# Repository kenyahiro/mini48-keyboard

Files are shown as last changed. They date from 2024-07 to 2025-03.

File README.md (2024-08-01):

# このキーボードについて
このキーボードは 19mmピッチ 48キーのロープロファイルキーボードです。
キースイッチは [kailh choc V1用ソケット](https://www.kailhswitch.com/mechanical-keyboard-switches/box-switches/choc-type-hot-swap-socket.html) を使用します。

マイコンには [AE-RP2040](https://akizukidenshi.com/catalog/g/g117542/) を使用します。

ファームウェアは [kmk_firmware](https://github.com/KMKfw/kmk_firmware) を使います。

# 部品表

| レフデス | 型名 | 数量 | 備考 |
|---|---|---|---|
| D1 - D48 | 1N4148W | 48 | |
| SW1 - SW48 | CPG135001S30 | 48 | Choc Type Hot Swap Socket |
| U1 | AE-RP2040 | 1 | RP2040マイコンボード |

この他に, kailh choc V1キースイッチ、 choc V1用キーキャップが必要です。
また、 基板を固定するためM2の支柱とネジを使います。

# マイコンの動作確認
組み立ての前にマイコンボードの動作確認を行います。
マイコンボードに [CircuitPython](https://circuitpython.org/board/raspberry_pi_pico/) を書き込みます。

書き込み後、 [Thonny](https://thonny.org/)等でCircuitPythonが動いていることを確認します。

# 組み立て

## ダイオードのハンダ付け
はじめに, D1 - D48 のダイオードをハンダ付けします。
アノードとカソードの向きを間違えないように注意してください。

## キーソケットのハンダ付け
次にkailh choc V1用キーソケットをハンダ付けします。
キーソケットには向きがあります。 基板のシルクを参考にして、間違えないようにハンダ付けしてください。

## マイコンボードの取り付け
マイコンボードの取り付け方法は、直付け または ピンソケット の選択ができます。

直付けの場合、キーボード裏の厚みを薄くできます。しかし、マイコンボードが故障したときに交換が難しくなります。

ピンソケットを使用した場合、キーボード裏の厚みがピンソケット分増加します。マイコンボードの交換は容易です。

### マイコンボードの組み立て

マイコンボードに 細ピンヘッダ(AE-RP2040付属) または [基板用リードフレーム](https://akizukidenshi.com/catalog/g/g114883/) をハンダ付けします。

細ピンヘッダをハンダ付けする場合、 ブレッドボードを使うとハンダ付けしやすいです。

リードフレームをハンダ付けする場合、 垂直になるようにハンダ付けします。まず1ピンだけ仮止めして、角度を調整します。
垂直になったら、残りのピンをハンダ付けします。

念のため、マイコンボードの裏側に[ポリイミドテープ](https://akizukidenshi.com/catalog/r/rpolyimid/)を貼って絶縁します。

### マイコンボードの取り付け(直付けの場合)
マイコンボードの取り付け前に、ダイオードとキーソケットの向き、ハンダ不良が無いことを確認します。
特に、 マイコンボードの下になる D35, D36, SW35, SW36 は注意して確認します。

U1のスルーホールにマイコンボードを刺し込みます。マイコンボードの裏側とダイオード、キーソケットが接触していないことを確認します。

マイコンボードのハンダ付けをします。まず、1つのピンをハンダ付けして仮止めします。
マイコンボードが水平になっていることを確認します。水平でない場合、ハンダゴデで仮止めしたピンのハンダを温めて、水平になるように修正します。

仮止めでマイコンボードが水平になっていることを確認できたら、残りのピンをハンダ付けします。

### マイコンボードの取り付け(ソケットの場合)
[ピンソケット](https://akizukidenshi.com/catalog/g/g100241/)はマイコンボードのピン数に合せてカットします。

基板にピンソケットをハンダ付けします。ピンソケットは垂直になるようにハンダ付けします。まず1ピンだけ仮止めして、角度を調整します。
垂直になったら、残りのピンをハンダ付けします。

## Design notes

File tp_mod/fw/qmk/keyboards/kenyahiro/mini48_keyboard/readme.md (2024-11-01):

# mini48-keyboard

A customizable Hotswap keyboard.

* Keyboard Maintainer: [kenyahiro](https://github.com/kenyahiro)

Make example for this keyboard (after setting up your build environment):

    make kenyahiro/mini48-keyboard:default

## Bootloader

Enter the bootloader in 3 ways:

* **Bootmagic reset**: Hold down the key at (0,0) in the matrix
* **Physical reset button**: Double tap the reset button on the back of the PCB
* **Keycode in layout**: Press the key mapped to `QK_BOOT` if it is available

See the [build environment setup](https://docs.qmk.fm/#/getting_started_build_tools) and the [make instructions](https://docs.qmk.fm/#/getting_started_make_guide) for more information. Brand new to QMK? Start with our [Complete Newbs Guide](https://docs.qmk.fm/#/newbs).

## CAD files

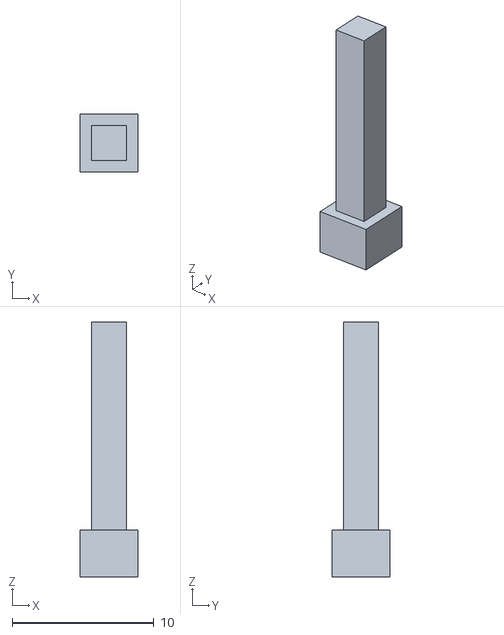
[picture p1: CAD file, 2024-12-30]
case/mini48-keyboard-case/tp-stem_t440-Body.stl
4.10 x 4.10 x 18.0

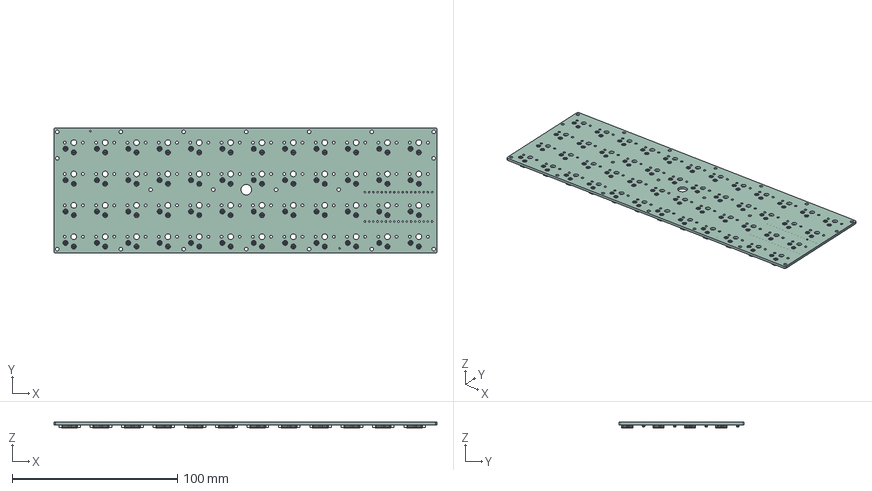
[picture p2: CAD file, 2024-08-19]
sch/mini48-keyboard/mini48-keyboard.step
232.0 x 76.0 x 3.45 mm
choc x 48
D_SOD_123 x 48
mini48-keyboard_PCB

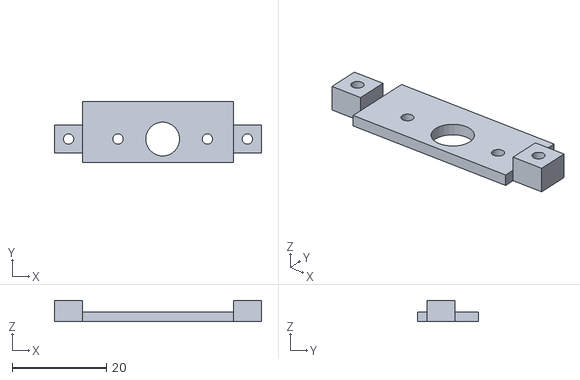
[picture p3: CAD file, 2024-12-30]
case/mini48-keyboard-case/tp_stay2-Body.stl
44.0 x 13.0 x 4.50

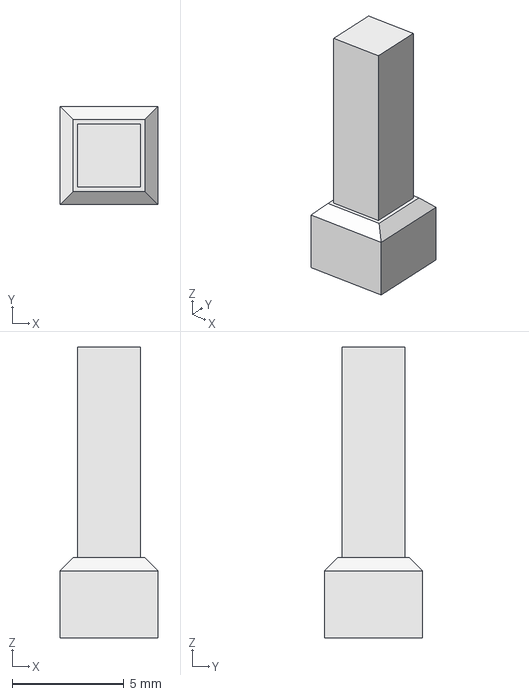
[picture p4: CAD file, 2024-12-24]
case/mini48-keyboard-case/tp-stem.FCStd
4.40 x 4.40 x 13.0 mm

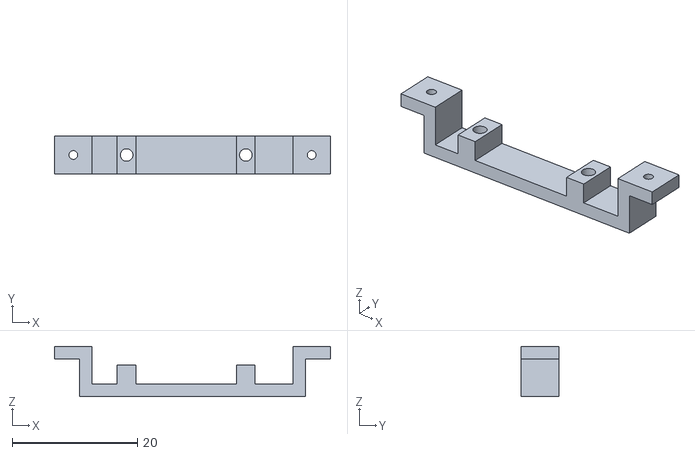
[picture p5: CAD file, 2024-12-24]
case/mini48-keyboard-case/tp_stay-Body.stl
44.0 x 6.00 x 8.00

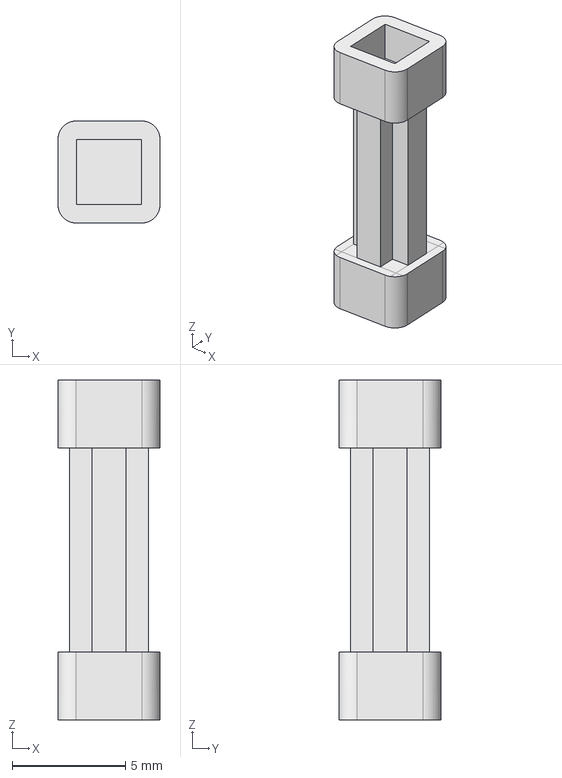
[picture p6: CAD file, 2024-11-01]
case/mini48-keyboard-case/tp-stem-test.FCStd
4.50 x 4.50 x 15.0 mm

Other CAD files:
case/mini48-keyboard-case/tp-stem_t440.FCStd
case/mini48-keyboard-case/tp_stay2.FCStd
case/mini48-keyboard-case/tp_stay.FCStd

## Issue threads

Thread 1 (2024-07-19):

コンスルーピンが使えない

kenyahiro, 2024-07-19:
マイコン基板のスルーホール径が大きいため、コンスルーピンが使えません。
通常のピンヘッダ、ICソケットは問題ありません。

コンスルーピンの推奨径は、Φ0.85 です。
https://www.mac8sdk.co.jp/uploads/entry_meta/file_value/1117/mac8_2022r103_jp-xb.pdf

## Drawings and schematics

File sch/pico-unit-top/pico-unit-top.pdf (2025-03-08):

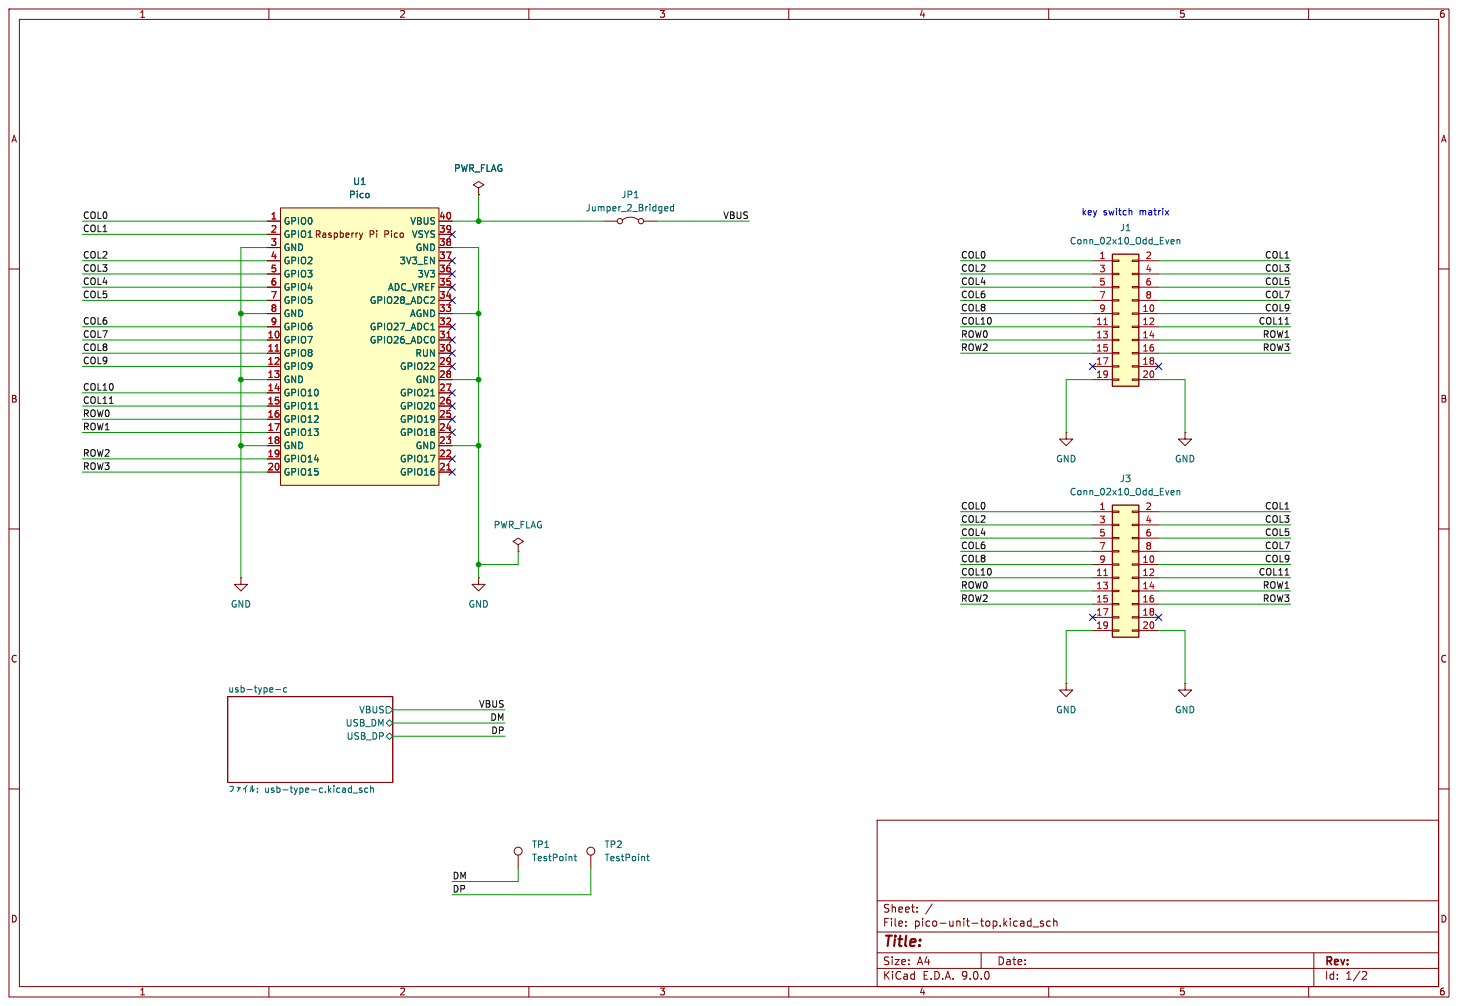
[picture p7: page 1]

VBUS
Id: 1/2 Title: File: pico-unit-top.kicad_sch Sheet: / USB_DM
USB_DP

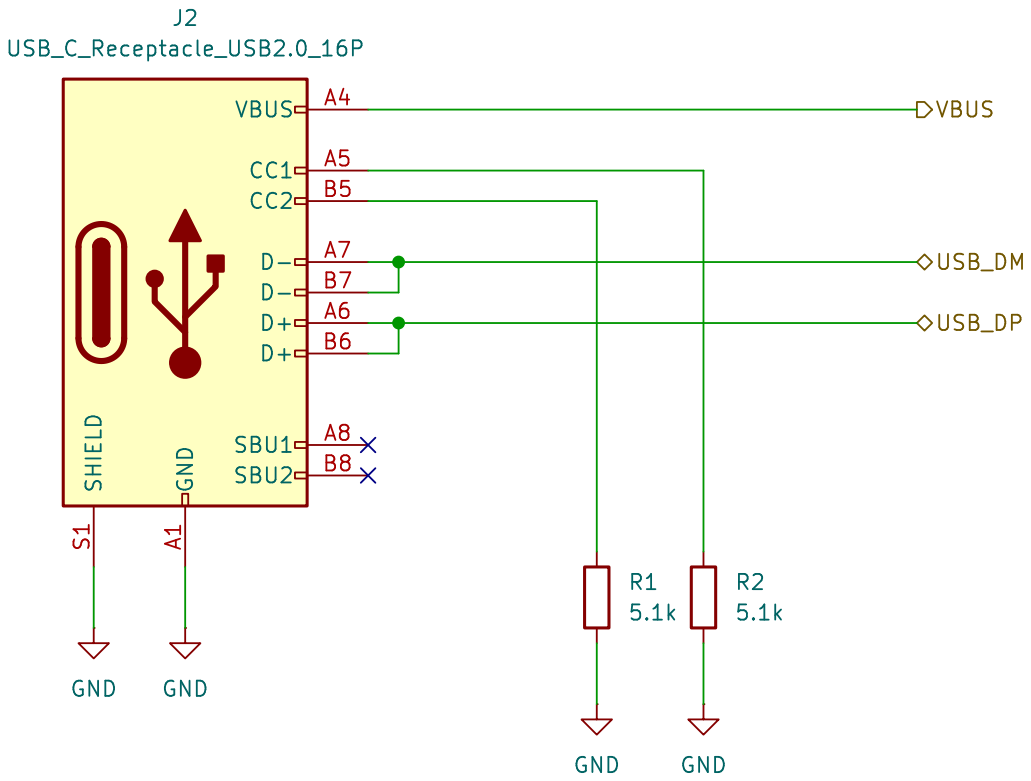
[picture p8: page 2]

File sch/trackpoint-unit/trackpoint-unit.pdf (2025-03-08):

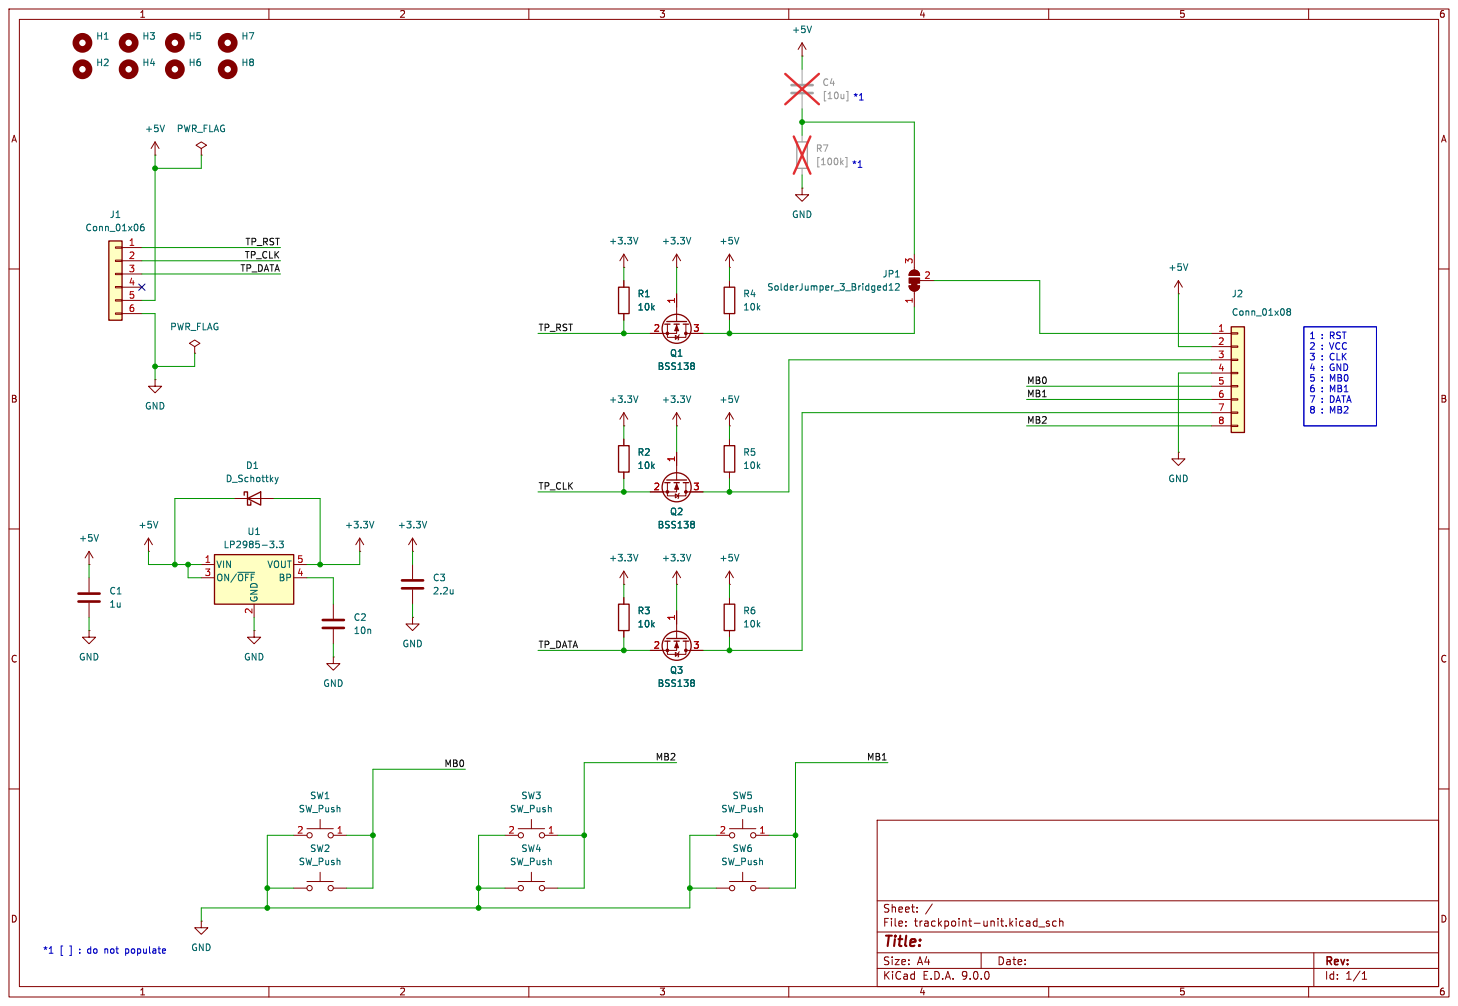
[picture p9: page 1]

Id: 1/1 Title: File: trackpoint-unit.kicad_sch Sheet: / R6

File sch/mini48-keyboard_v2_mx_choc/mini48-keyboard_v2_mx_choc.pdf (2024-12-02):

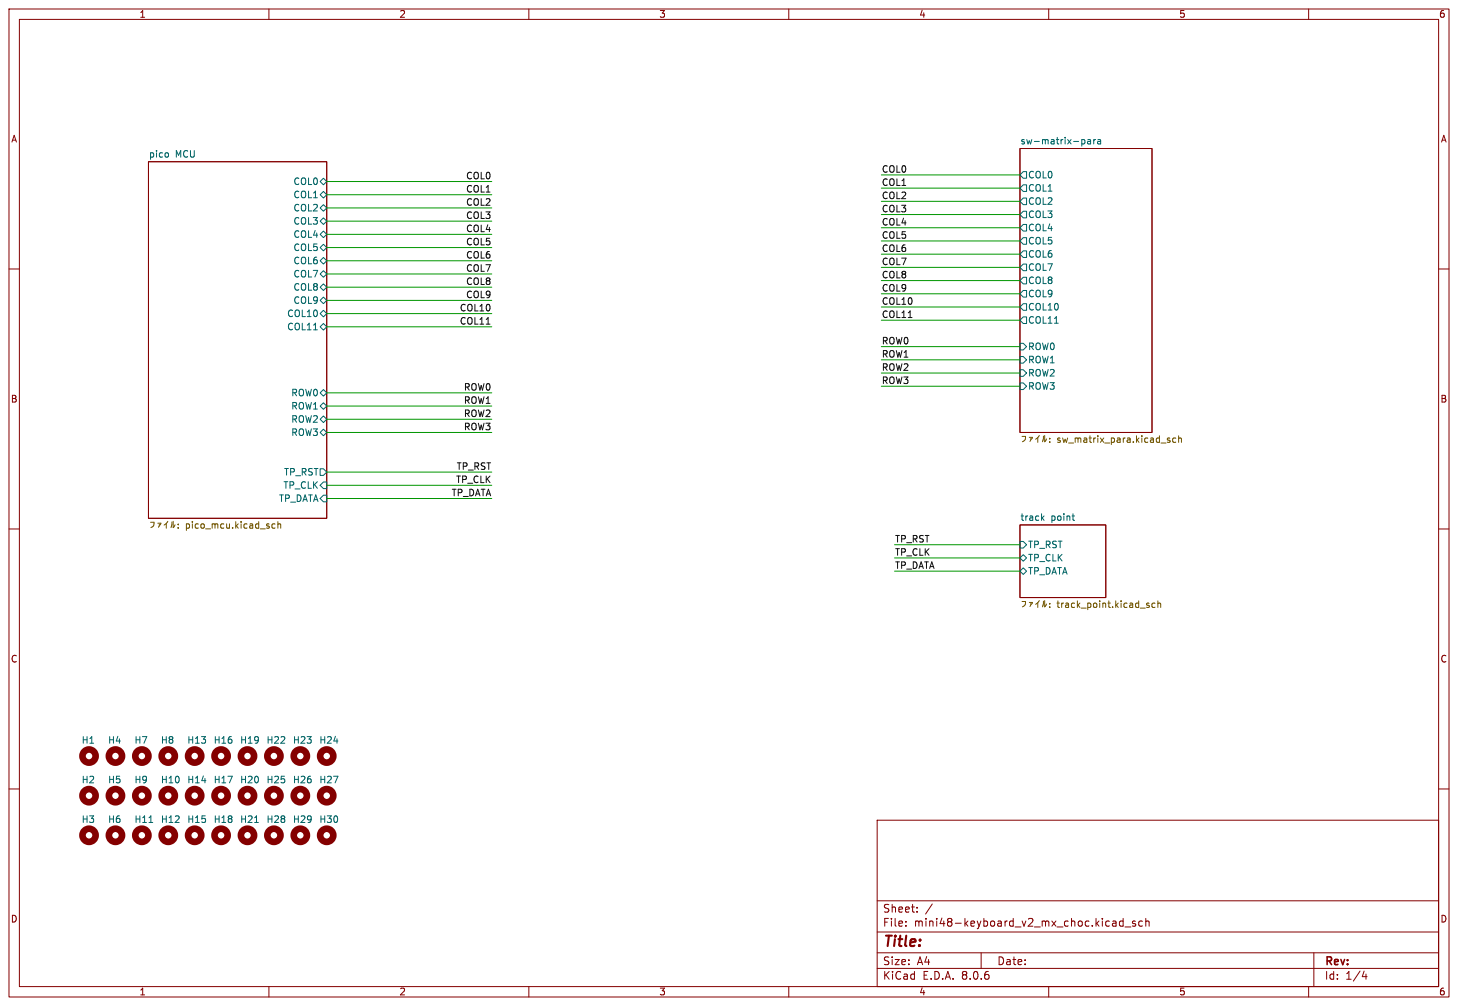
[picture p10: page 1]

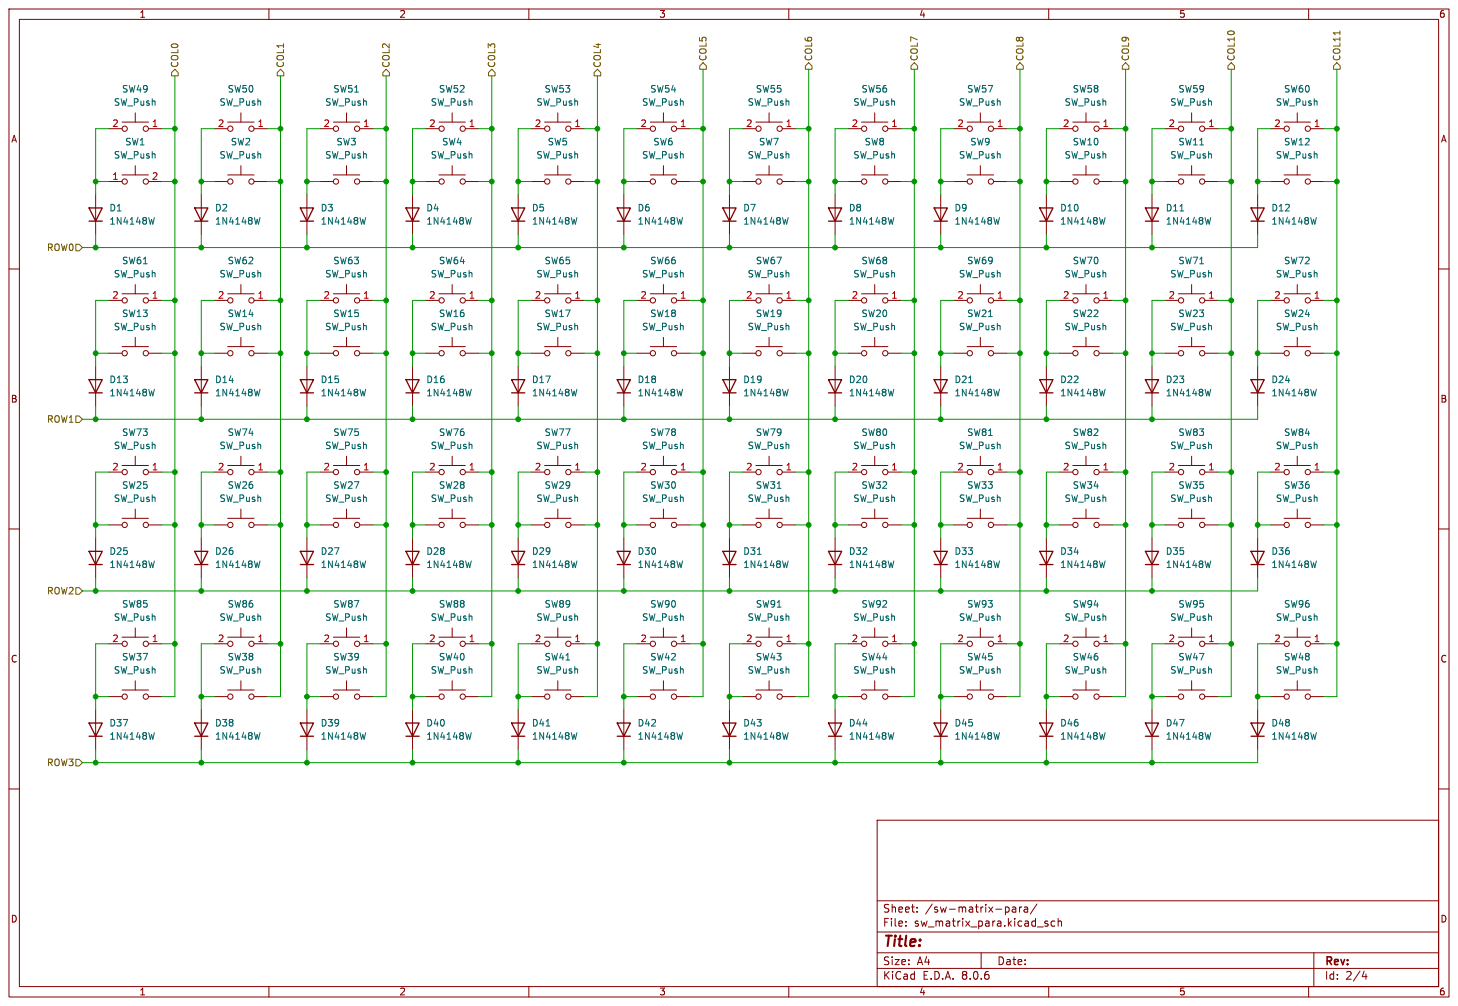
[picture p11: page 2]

Id: 2/4 Title: File: sw_matrix_para.kicad_sch Sheet: /sw-matrix-para/

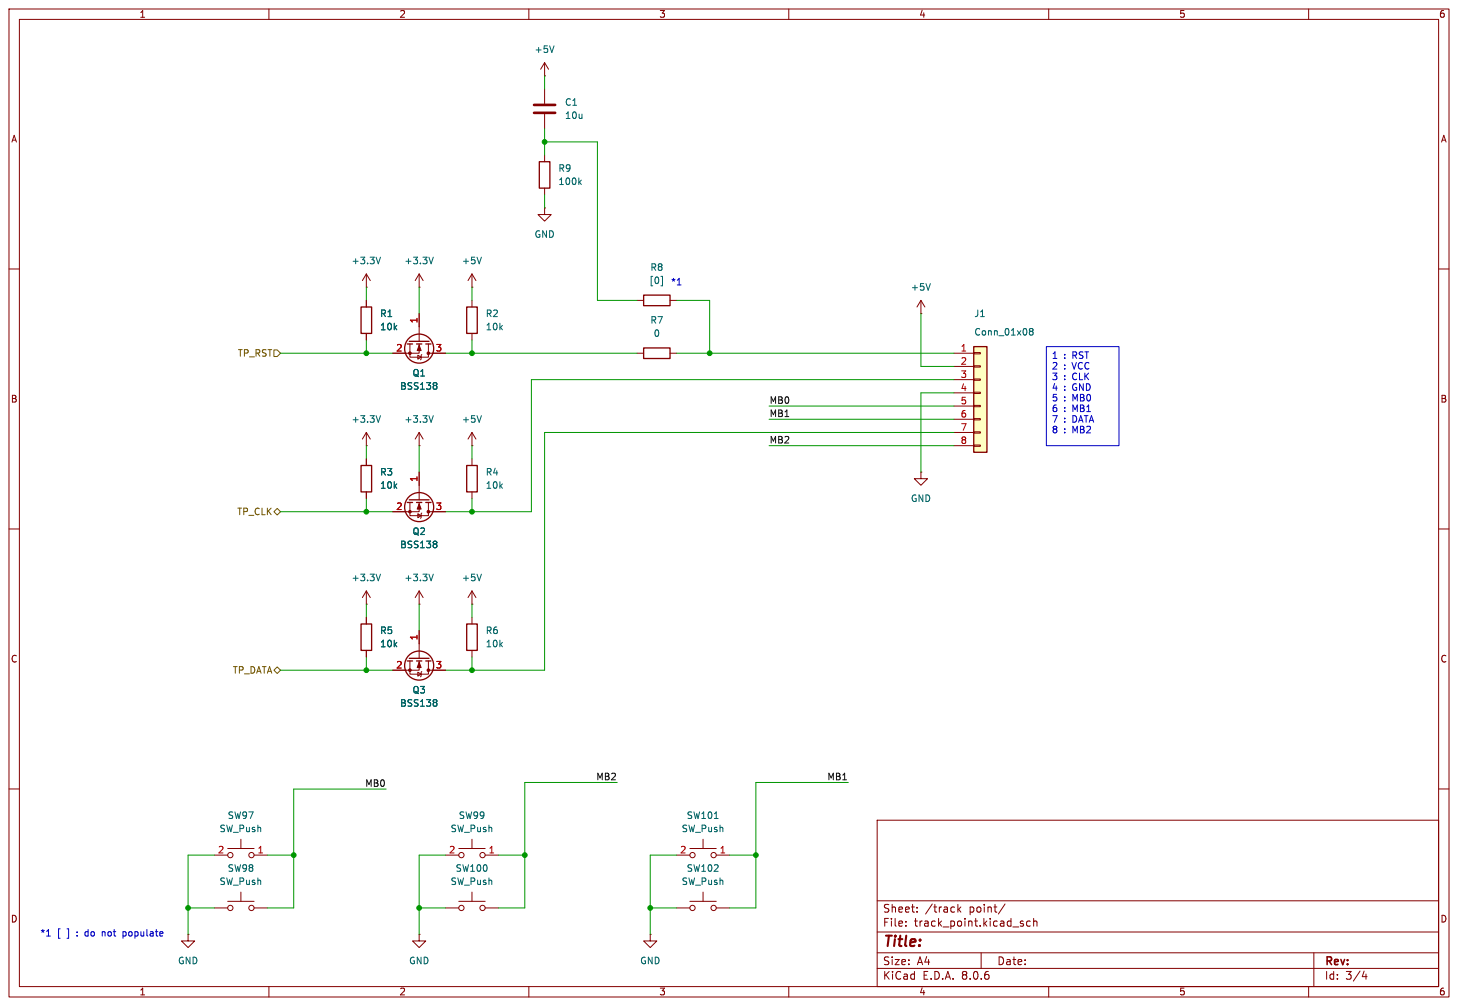
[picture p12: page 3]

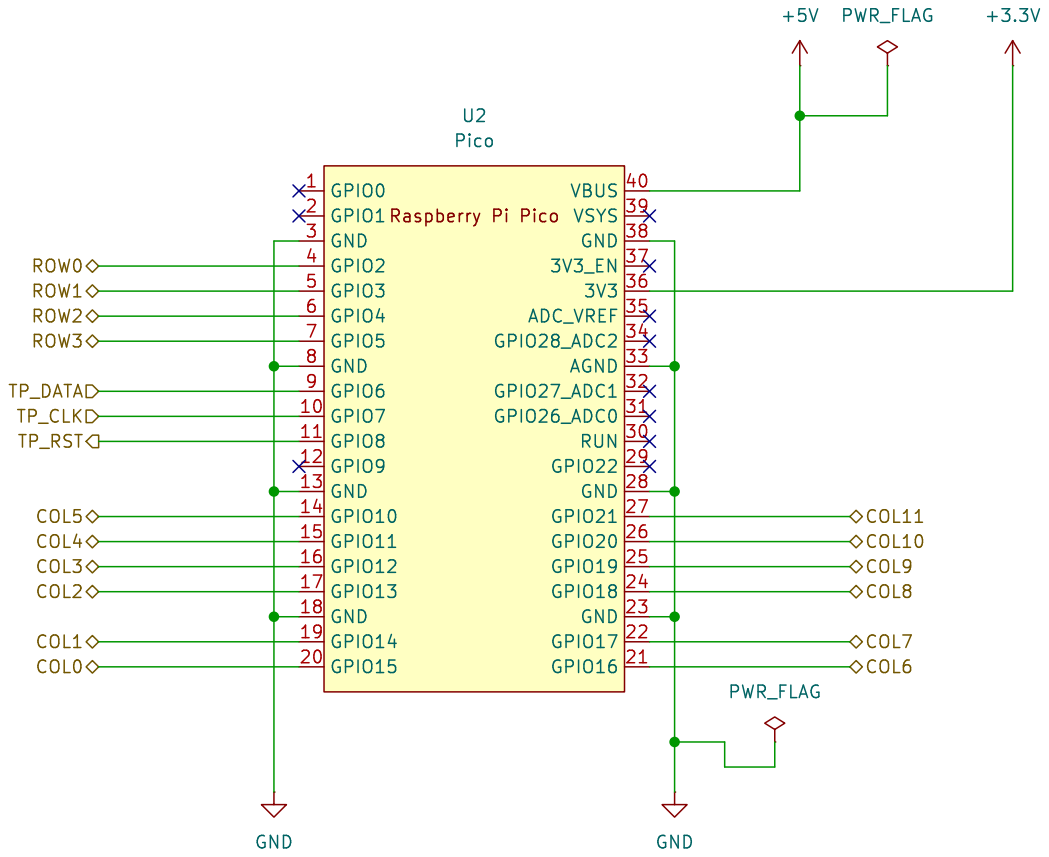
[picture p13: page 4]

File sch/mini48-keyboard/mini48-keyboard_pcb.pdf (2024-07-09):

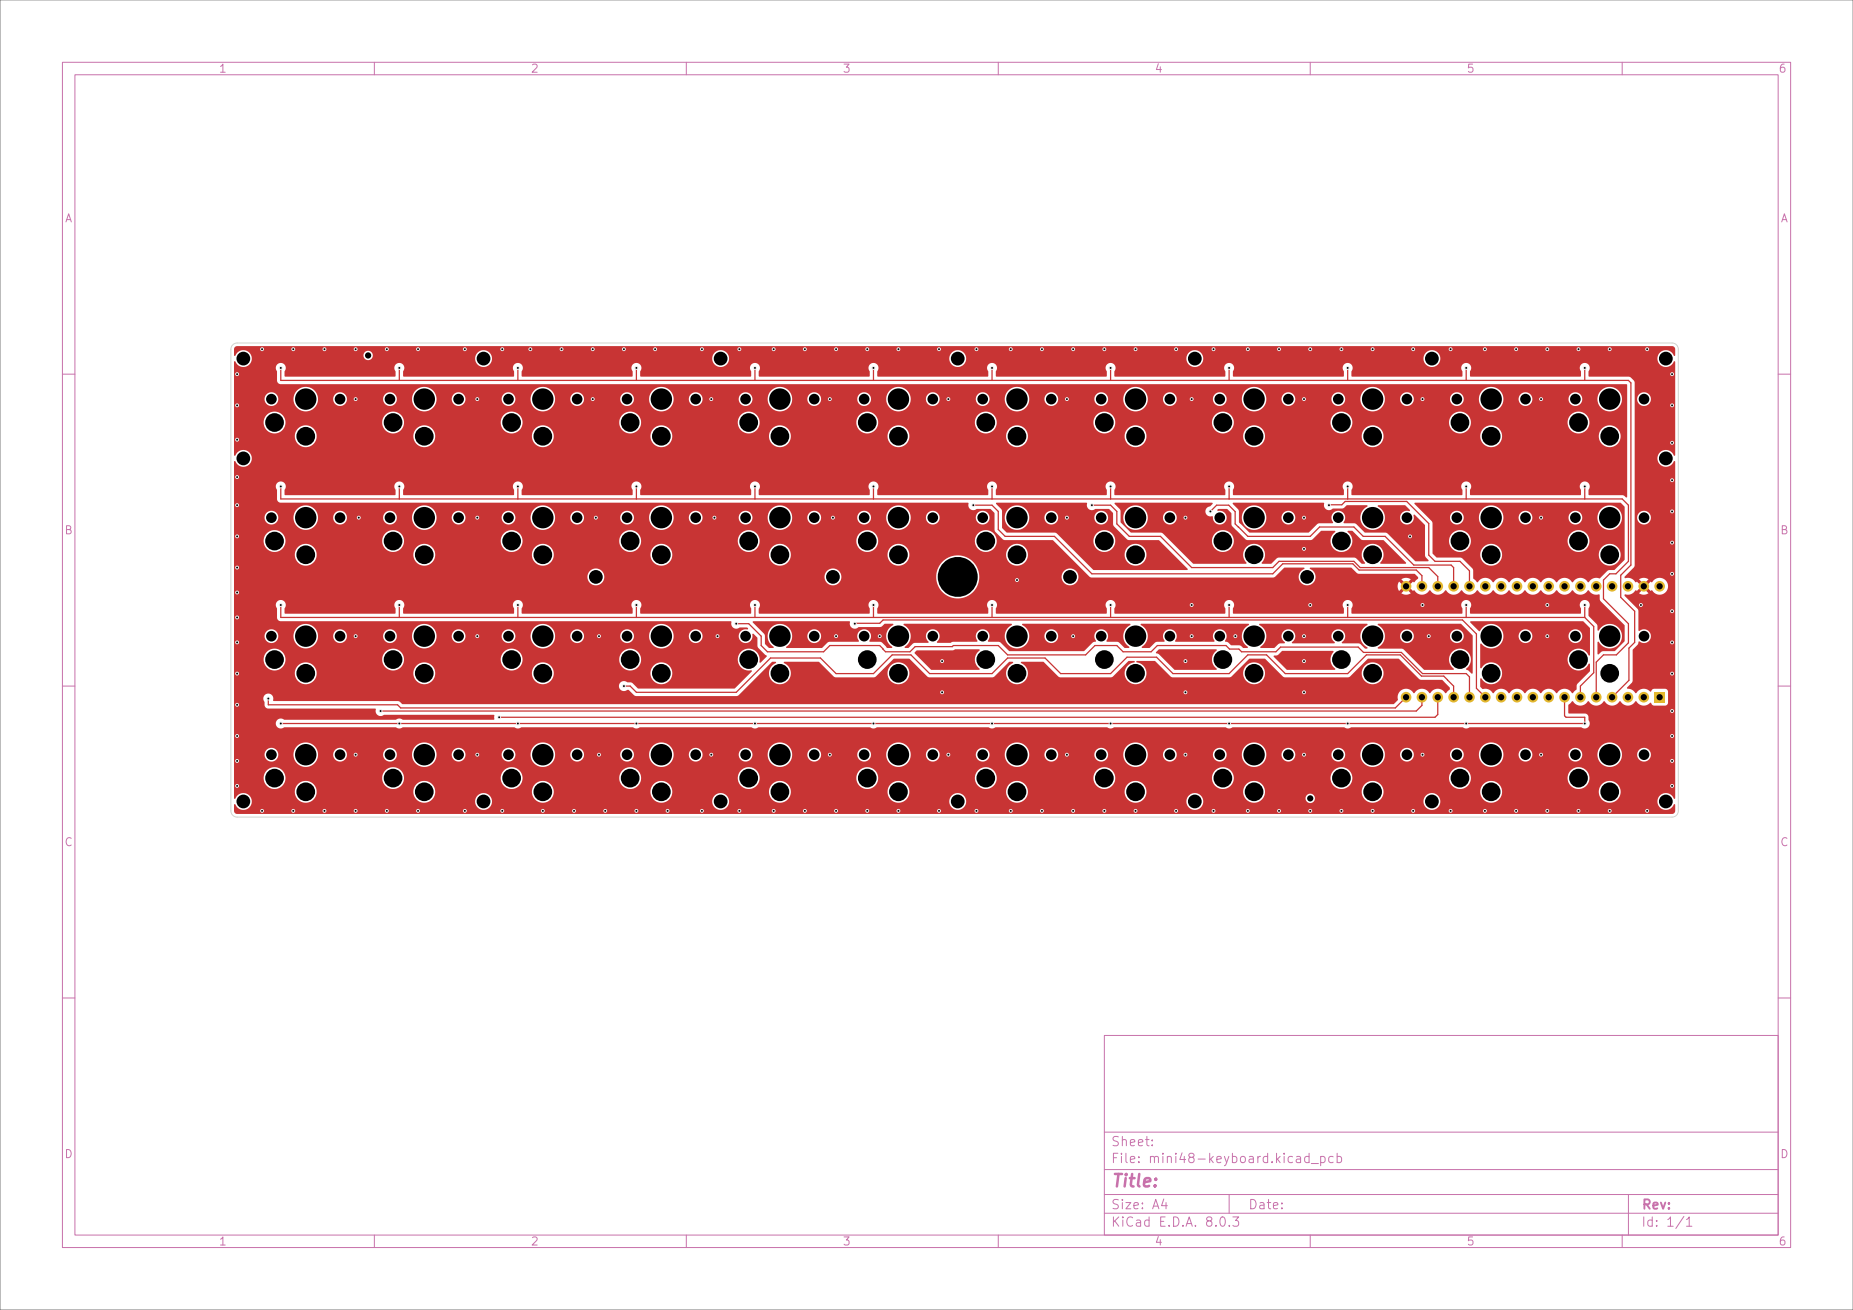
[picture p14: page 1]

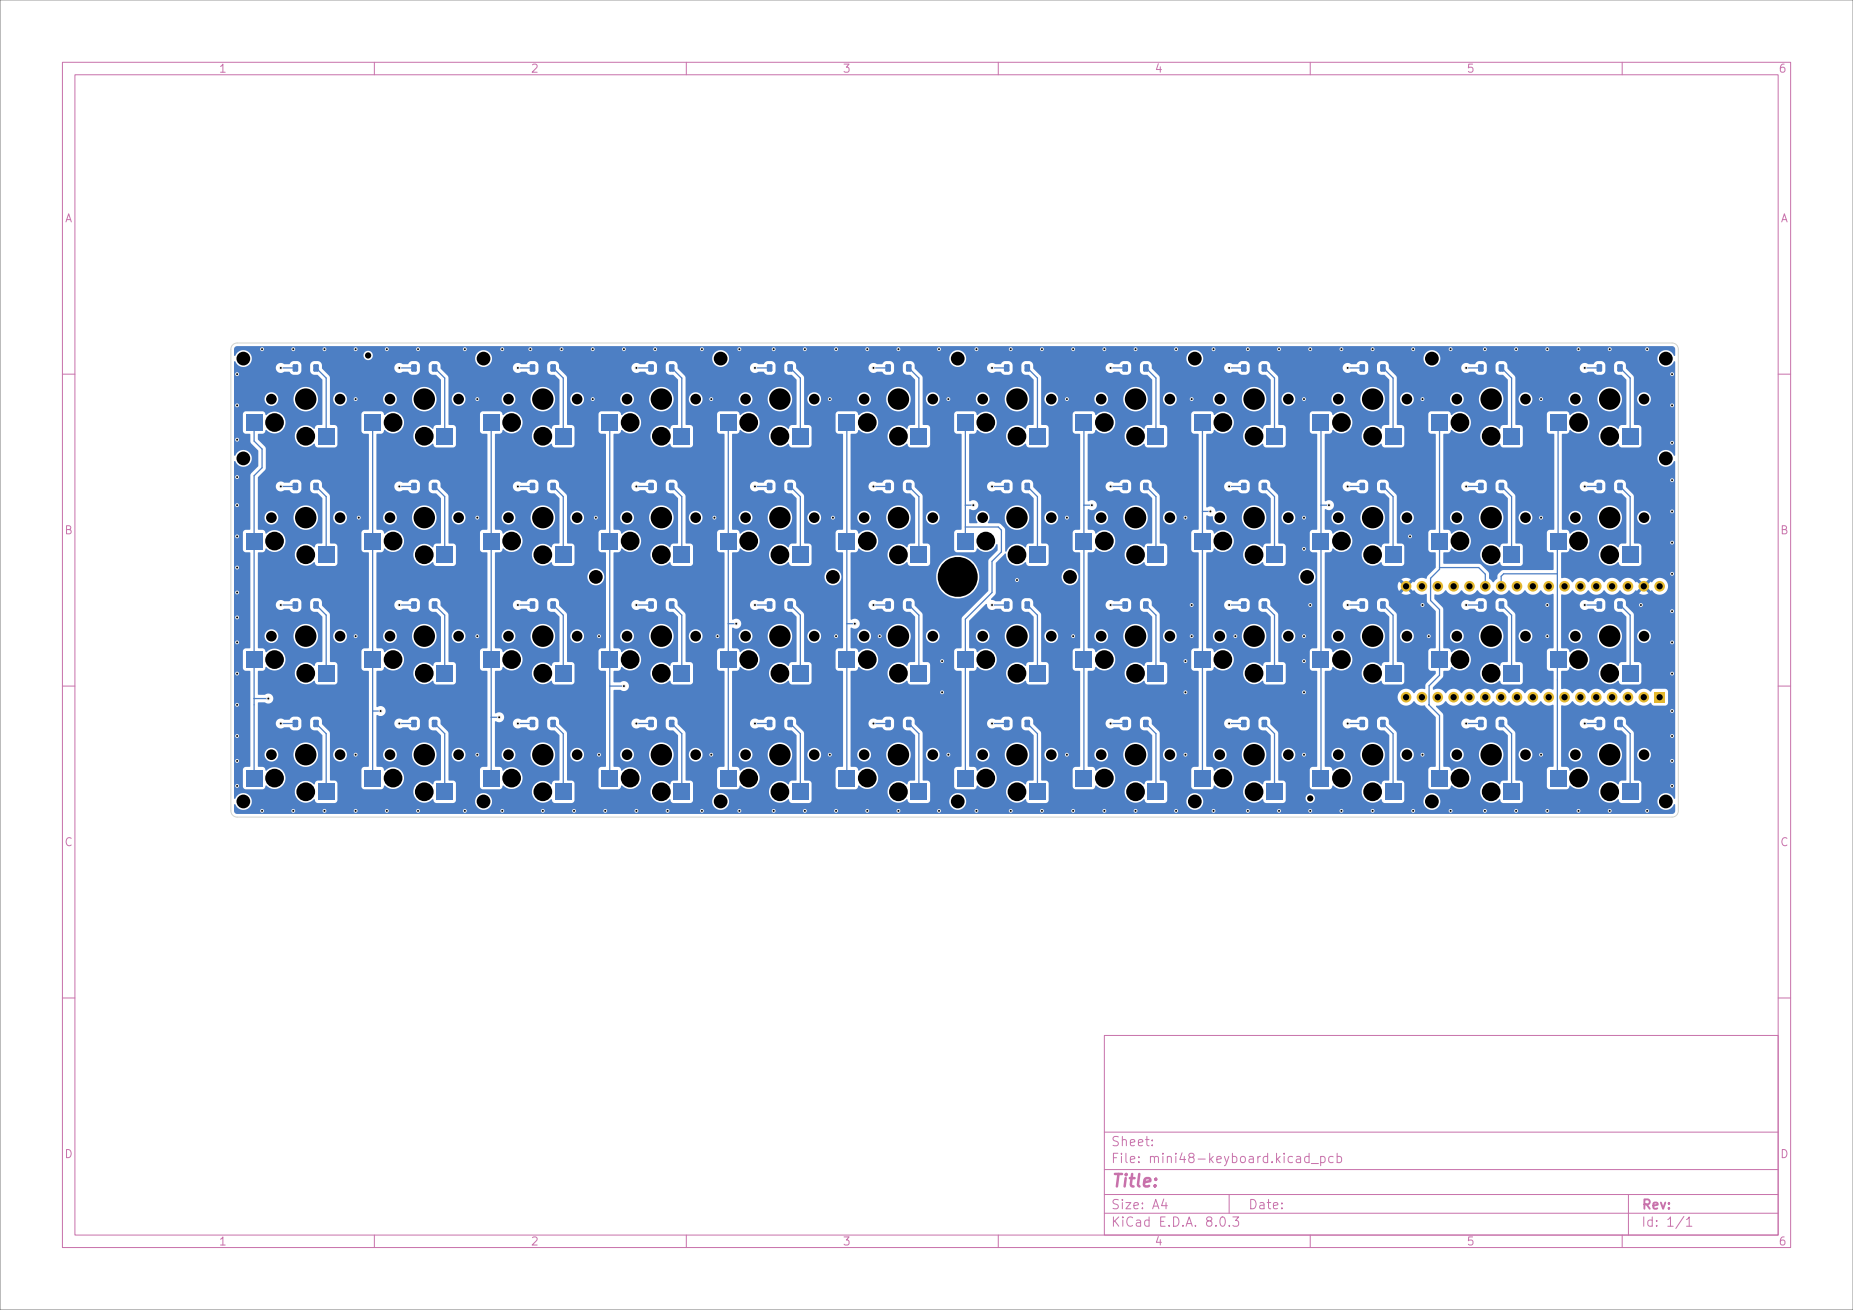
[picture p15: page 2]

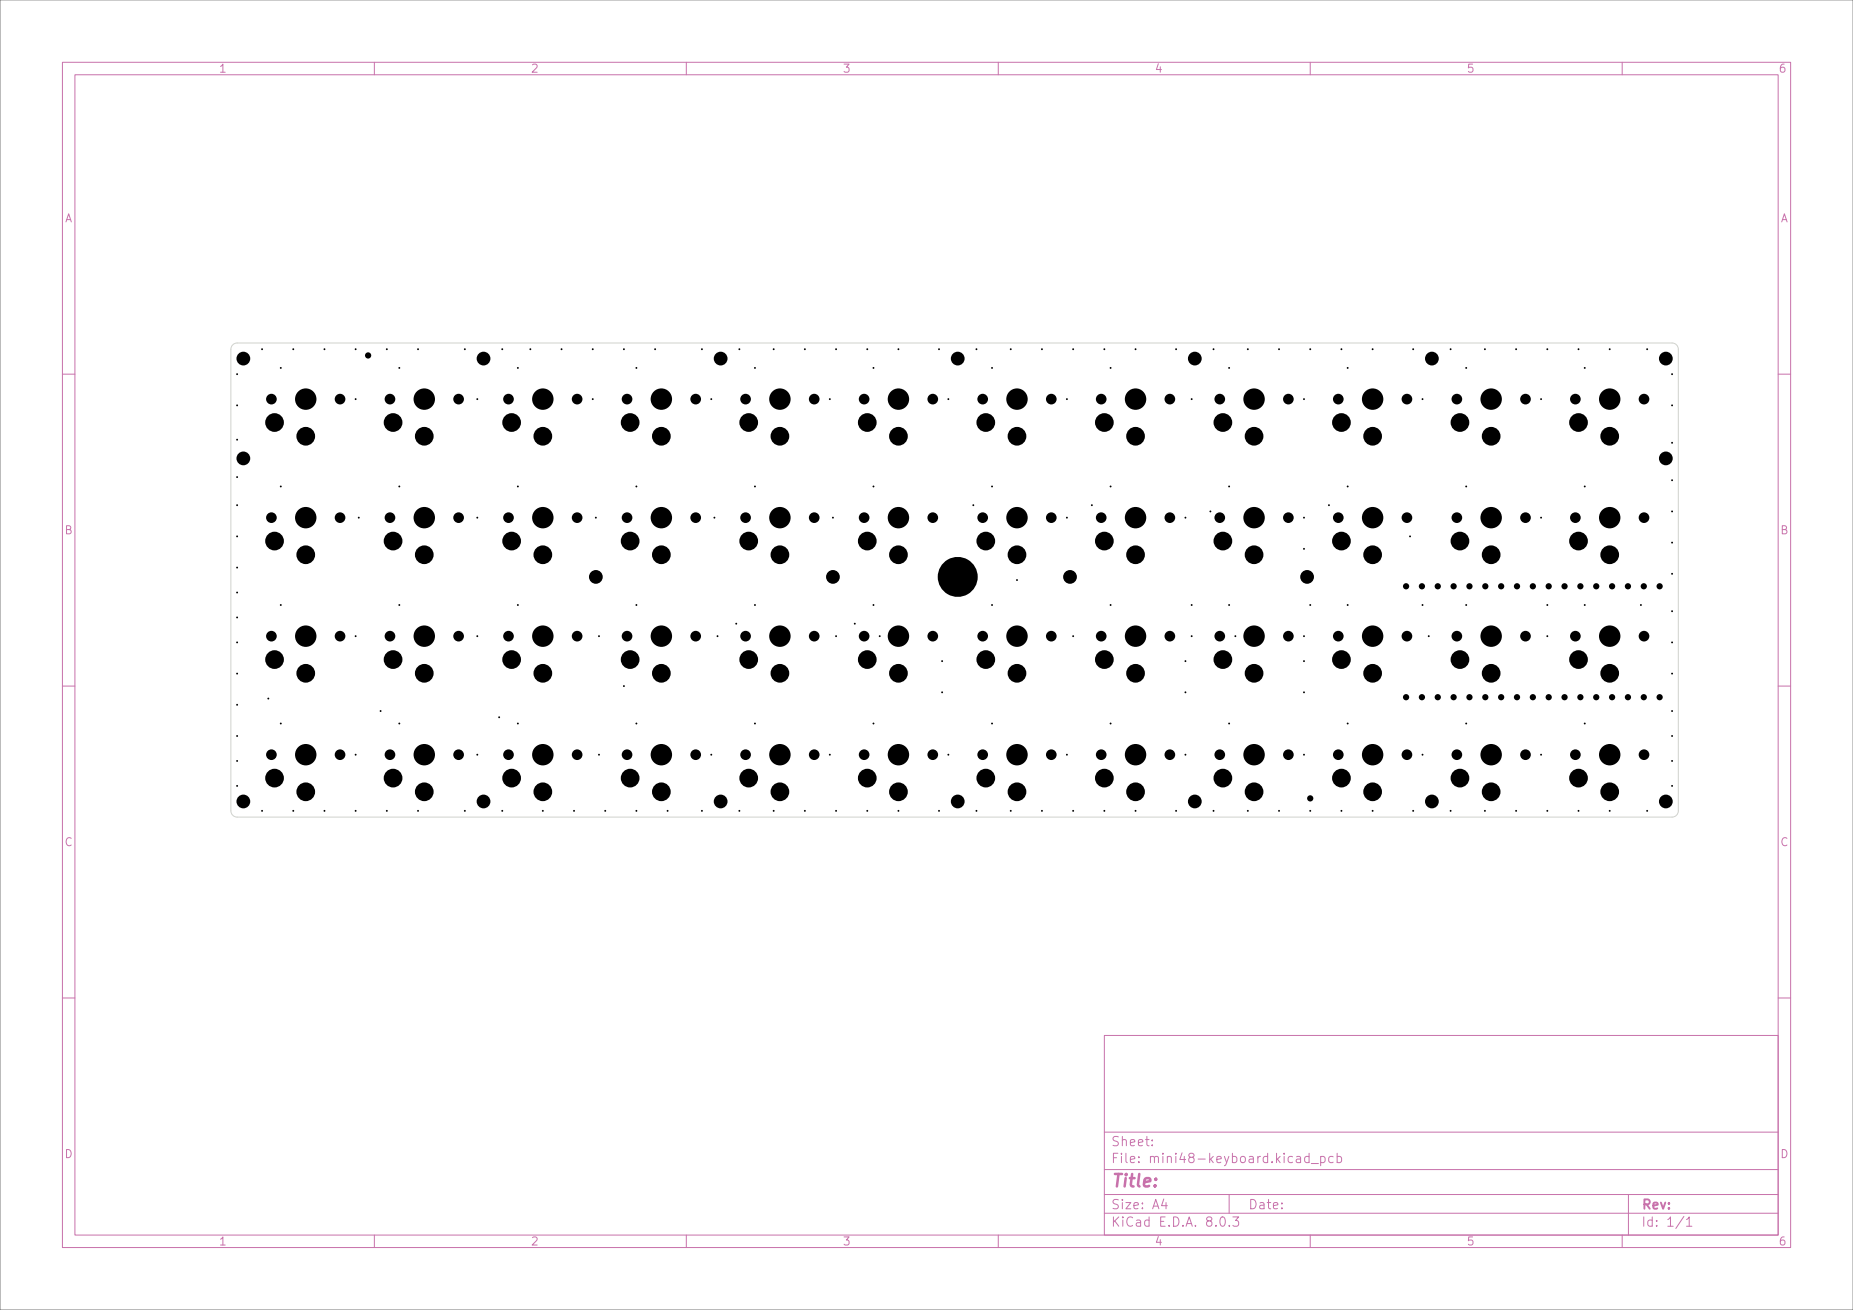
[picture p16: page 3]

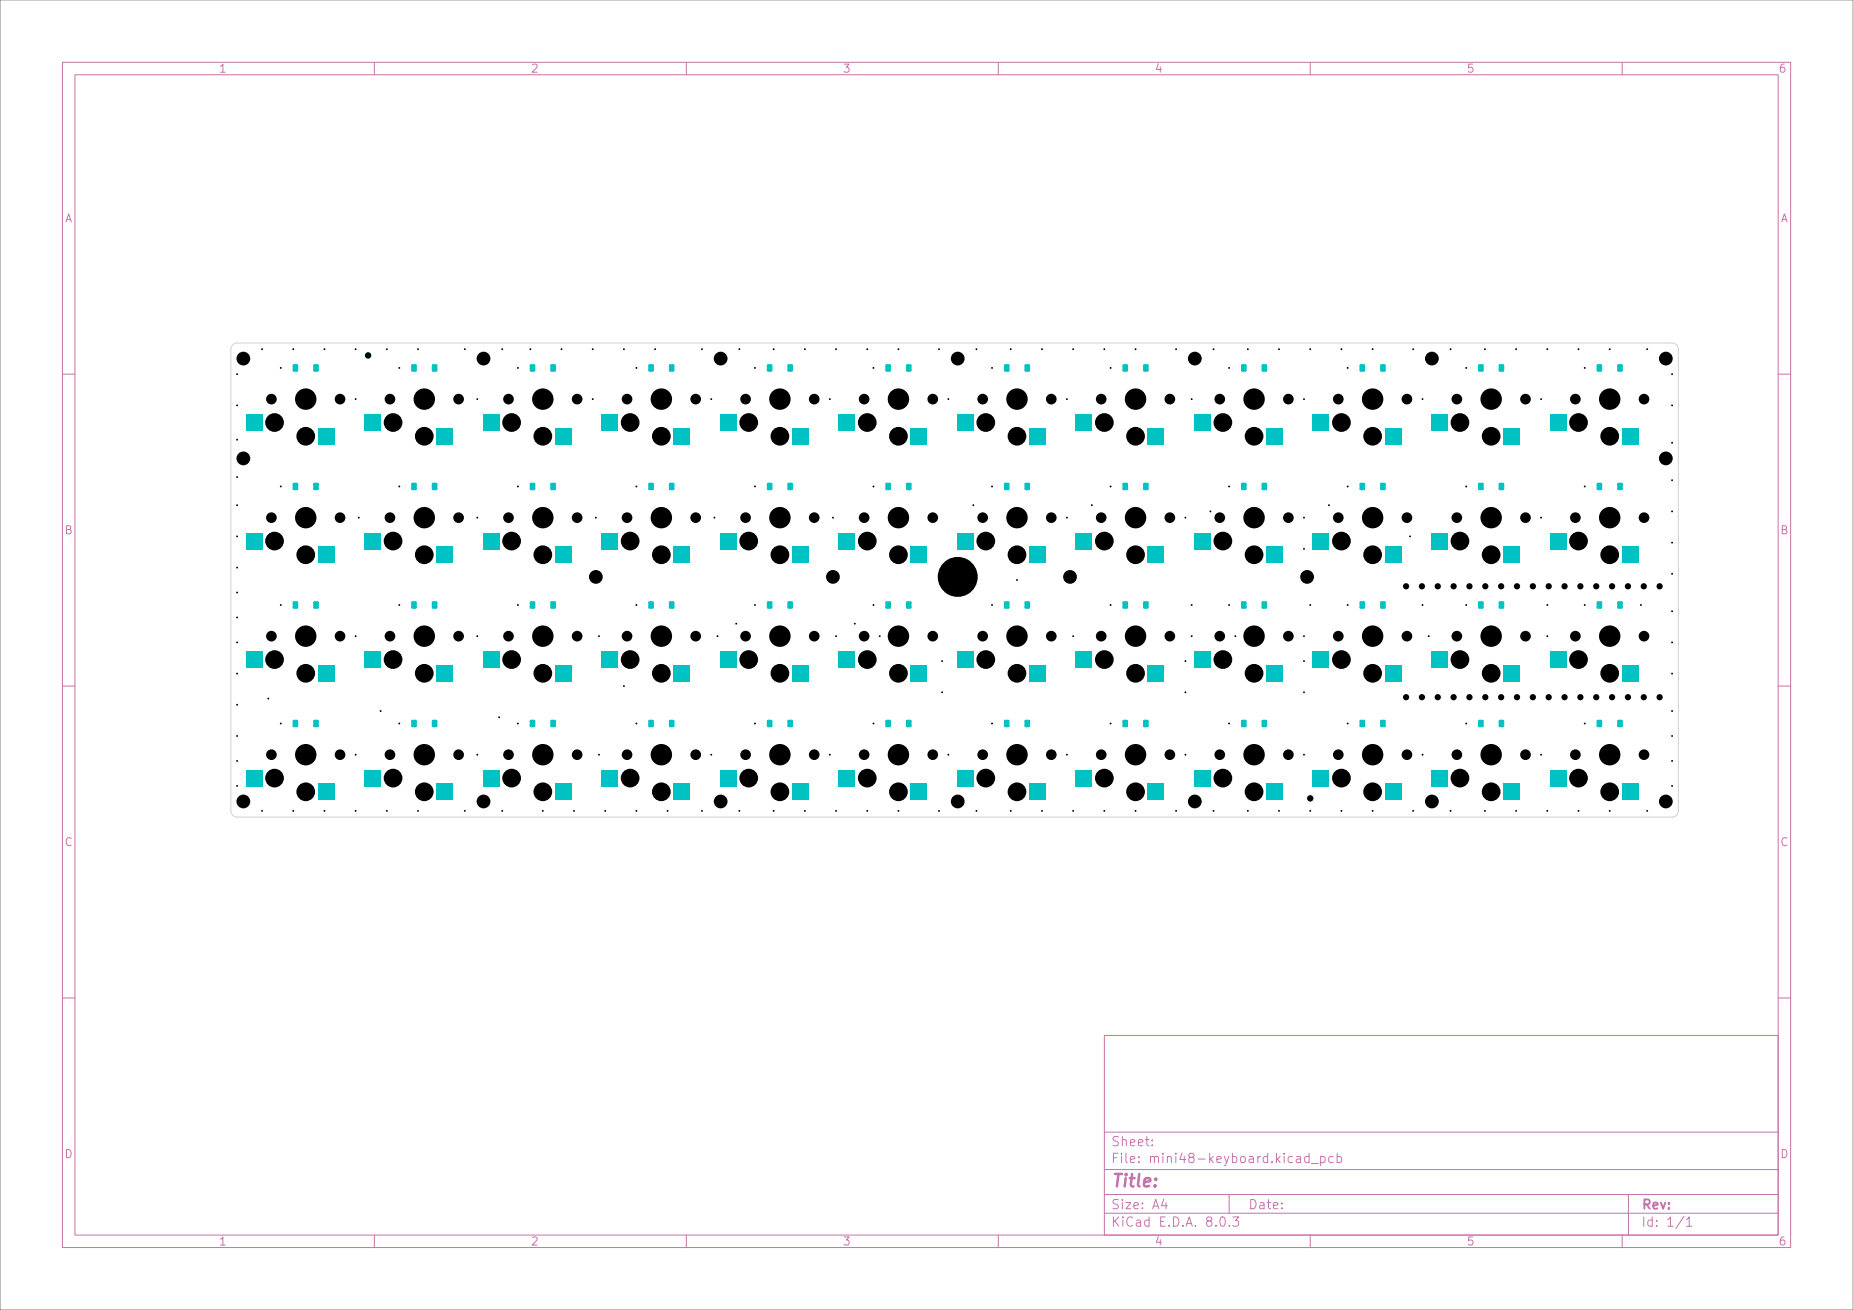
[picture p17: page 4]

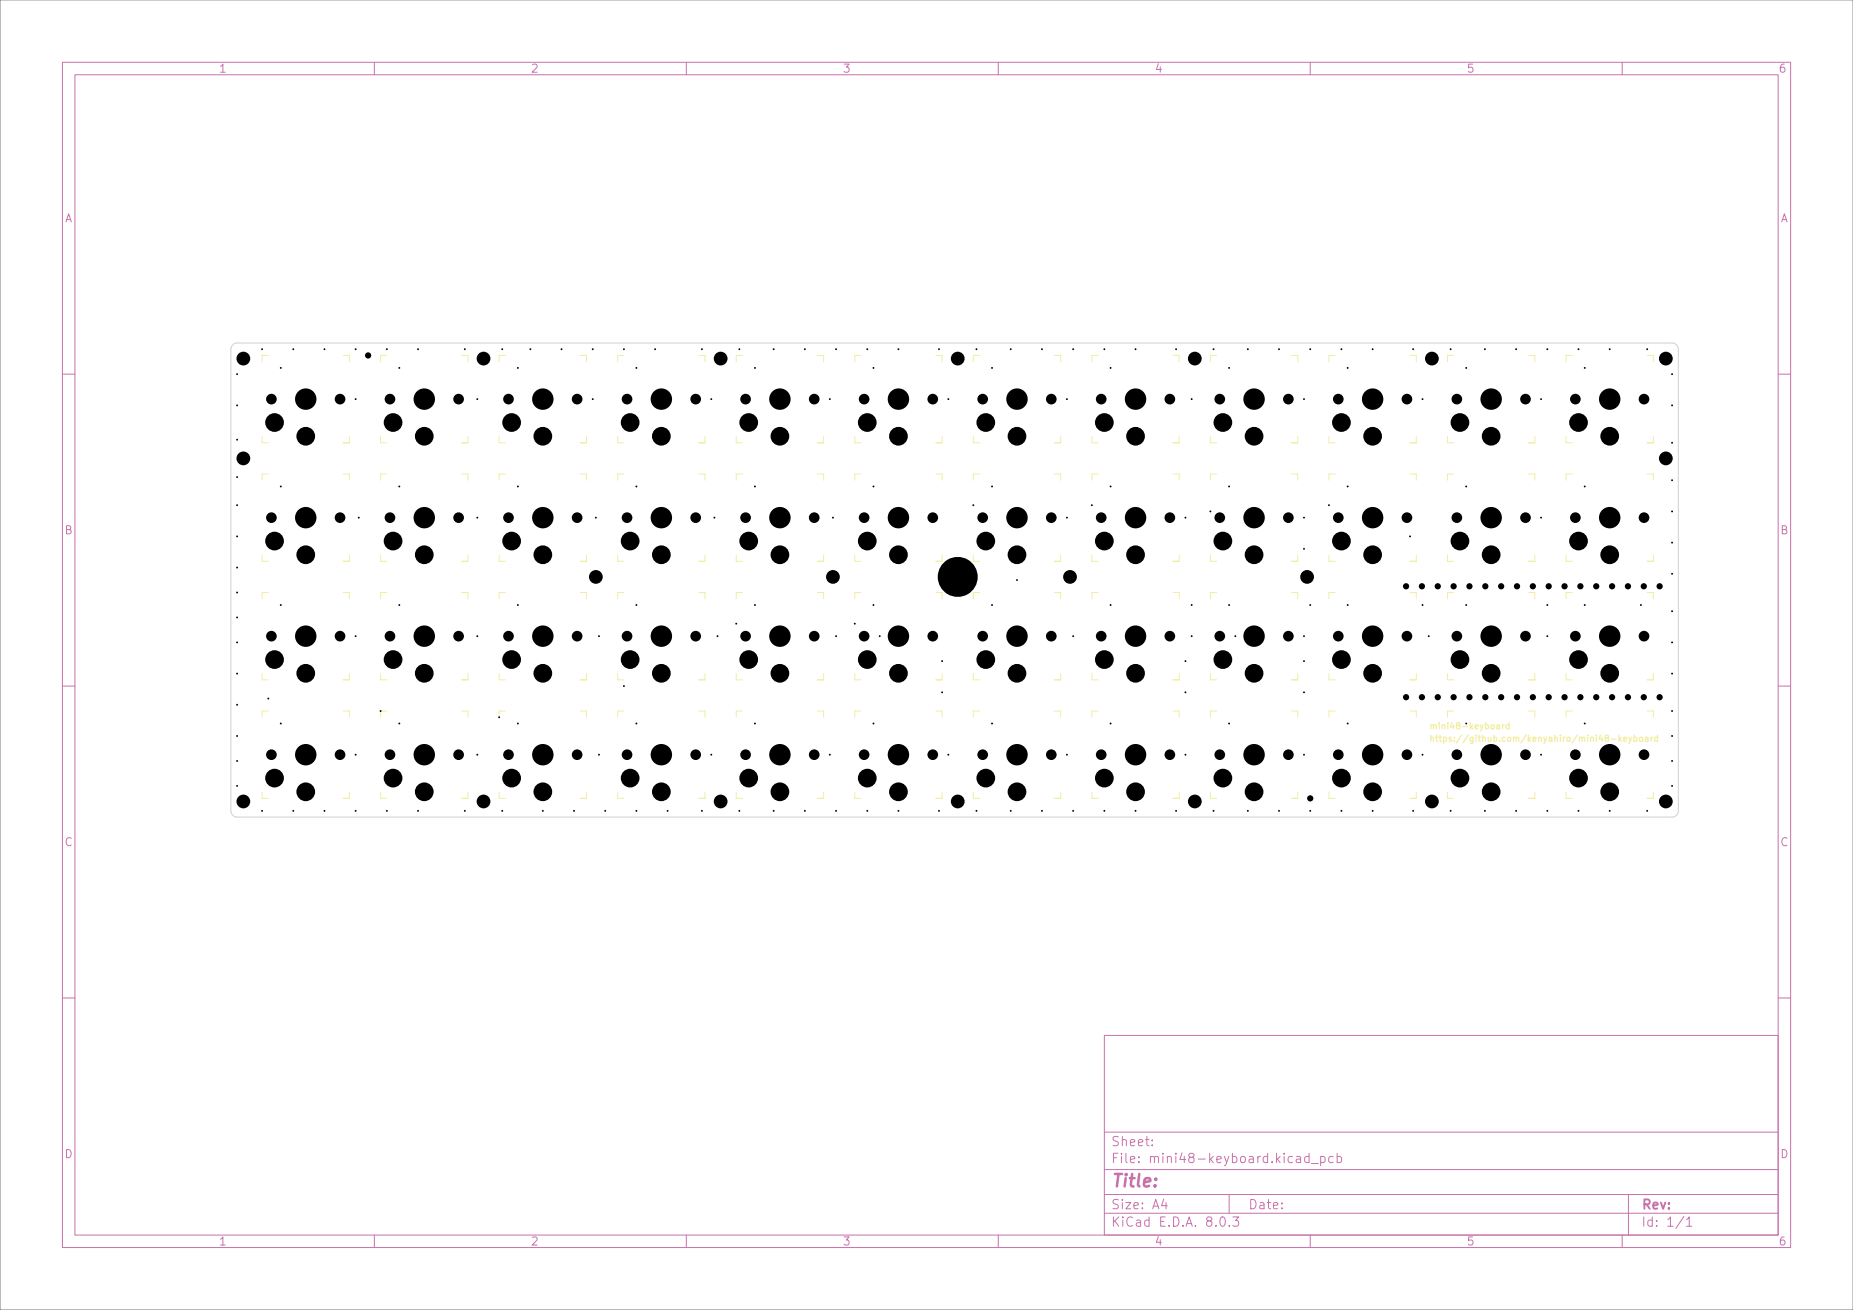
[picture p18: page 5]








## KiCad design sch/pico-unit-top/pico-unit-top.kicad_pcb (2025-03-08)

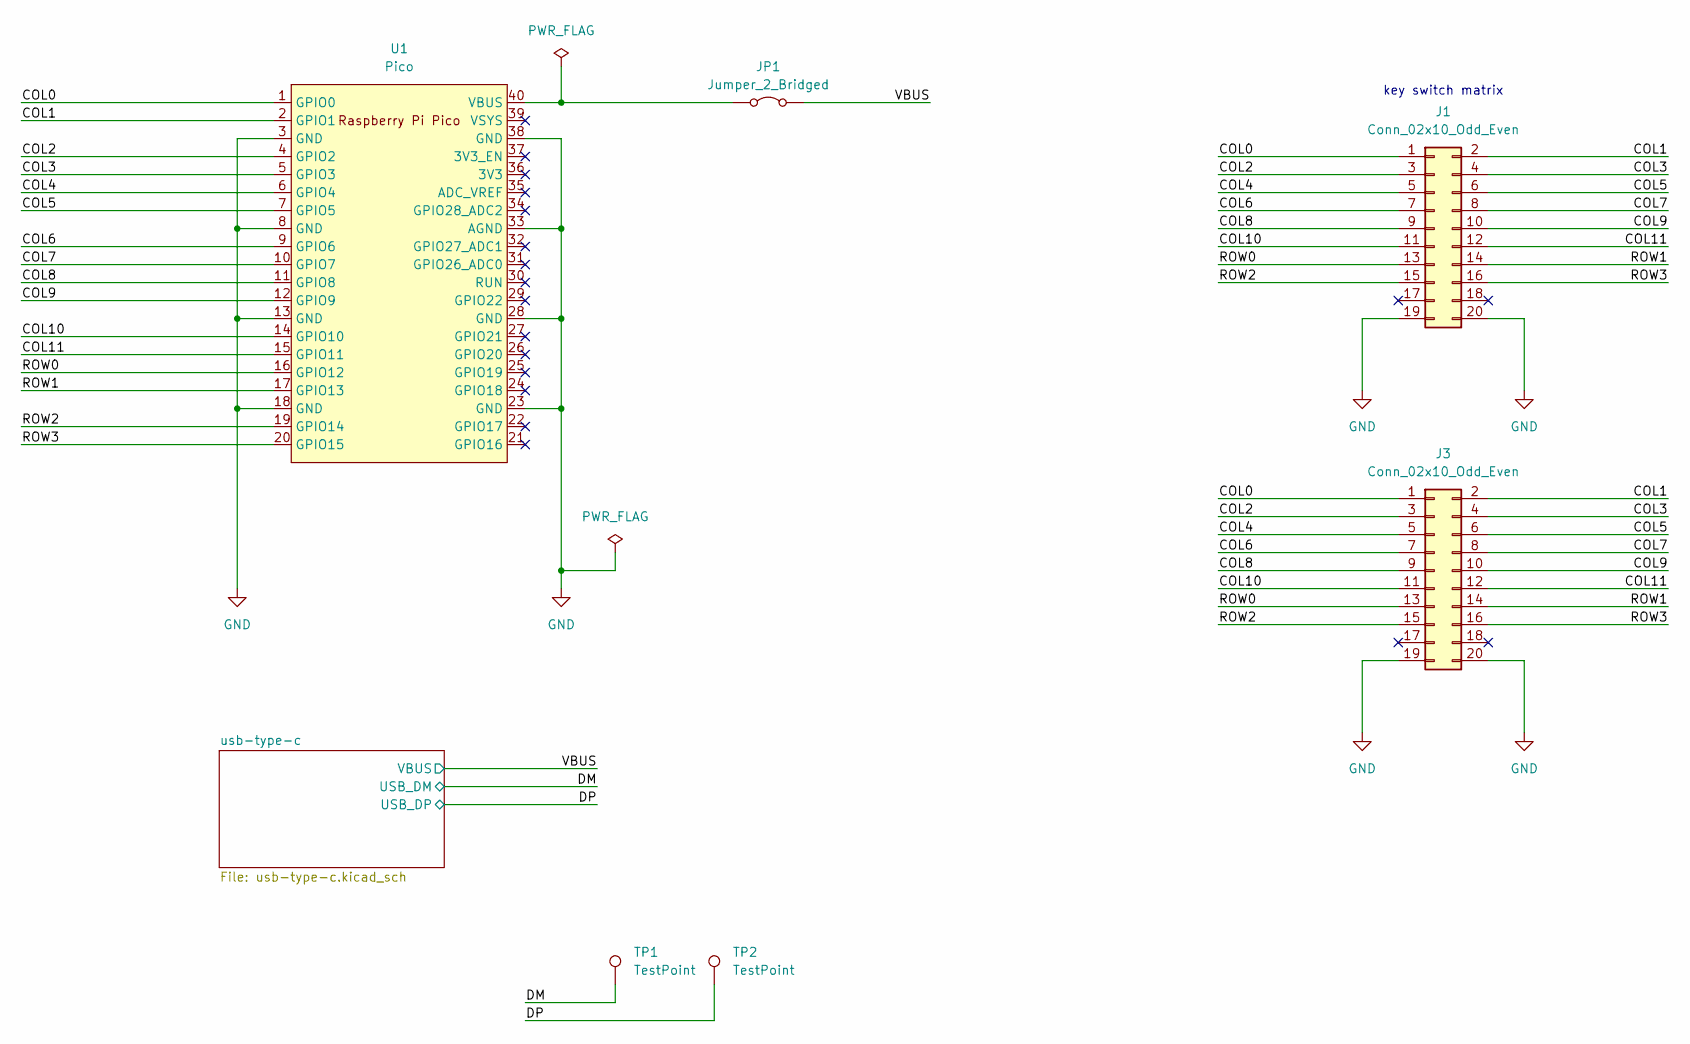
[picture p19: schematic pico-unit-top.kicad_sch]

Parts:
J1: Conn_02x10_Odd_Even; PinSocket_2x10_P2.54mm_Horizontal
J3: Conn_02x10_Odd_Even; PinSocket_2x10_P2.54mm_Vertical
JP1: Jumper_2_Bridged; SolderJumper-2_P1.3mm_Bridged_RoundedPad1.0x1.5mm
TP1, TP2: TestPoint; TestPoint_THTPad_2.0x2.0mm_Drill1.0mm
U1: Pico; pico_no_dbg_smd_th_p0.85

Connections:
/COL0: J1.1, J3.1, U1.1 (GPIO0)
/COL1: J1.2, J3.2, U1.2 (GPIO1)
/COL2: J1.3, J3.3, U1.4 (GPIO2)
/COL3: J1.4, J3.4, U1.5 (GPIO3)
/COL4: J1.5, J3.5, U1.6 (GPIO4)
/COL5: J1.6, J3.6, U1.7 (GPIO5)
/COL6: J1.7, J3.7, U1.9 (GPIO6)
/COL7: J1.8, J3.8, U1.10 (GPIO7)
/COL8: J1.9, J3.9, U1.11 (GPIO8)
/COL9: J1.10, J3.10, U1.12 (GPIO9)
/COL10: J1.11, J3.11, U1.14 (GPIO10)
/COL11: J1.12, J3.12, U1.15 (GPIO11)
/DM: TP1.1; also elsewhere on the board
/DP: TP2.1; also elsewhere on the board
/ROW0: J1.13, J3.13, U1.16 (GPIO12)
/ROW1: J1.14, J3.14, U1.17 (GPIO13)
/ROW2: J1.15, J3.15, U1.19 (GPIO14)
/ROW3: J1.16, J3.16, U1.20 (GPIO15)
/VBUS: JP1.2 (B); also elsewhere on the board
GND: J1.19, J1.20, J3.19, J3.20, U1.3 (GND), U1.8 (GND), U1.13 (GND), U1.18 (GND), U1.23 (GND), U1.28 (GND), U1.33 (AGND), U1.38 (GND); also elsewhere on the board
unnamed: JP1.1 (A), U1.40 (VBUS)

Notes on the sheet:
key switch matrix

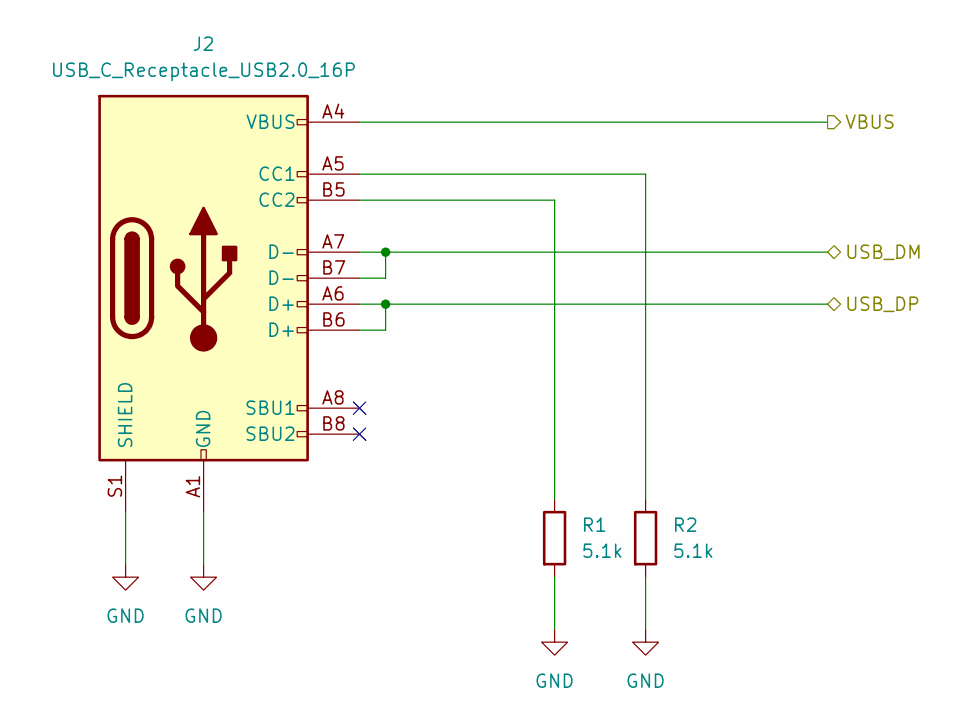
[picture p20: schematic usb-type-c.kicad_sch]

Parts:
J2: USB_C_Receptacle_USB2.0_16P; USB_C_Receptacle_G-Switch_GT-USB-7010ASV
R1, R2: 5.1k; R_0603_1608Metric

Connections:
/DM: J2.A7 (D-), J2.B7 (D-); also elsewhere on the board
/DP: J2.A6 (D+), J2.B6 (D+); also elsewhere on the board
/VBUS: J2.A4 (VBUS), J2.A9 (VBUS), J2.B4 (VBUS), J2.B9 (VBUS); also elsewhere on the board
GND: J2.A1 (GND), J2.A12 (GND), J2.B1 (GND), J2.B12 (GND), J2.S1 (SHIELD), R1.2, R2.2; also elsewhere on the board
unnamed: J2.A5 (CC1), R2.1
unnamed: J2.B5 (CC2), R1.1

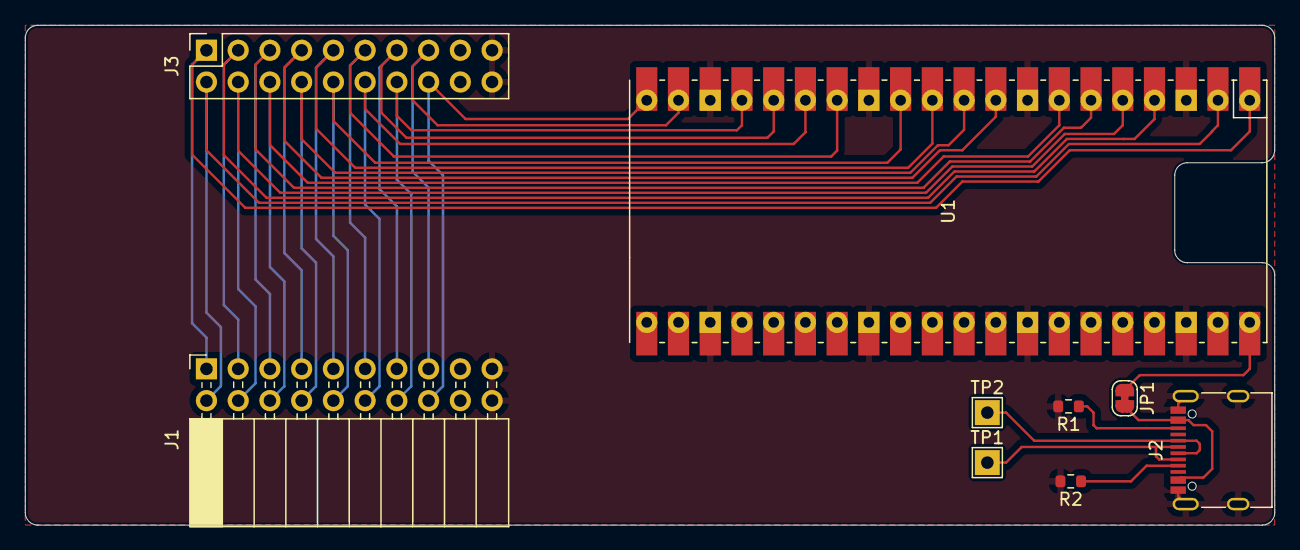
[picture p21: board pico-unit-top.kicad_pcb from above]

Board: 2 copper layers, 100.0 x 40.0 mm, 9 parts (0 on the bottom side), 23 nets.

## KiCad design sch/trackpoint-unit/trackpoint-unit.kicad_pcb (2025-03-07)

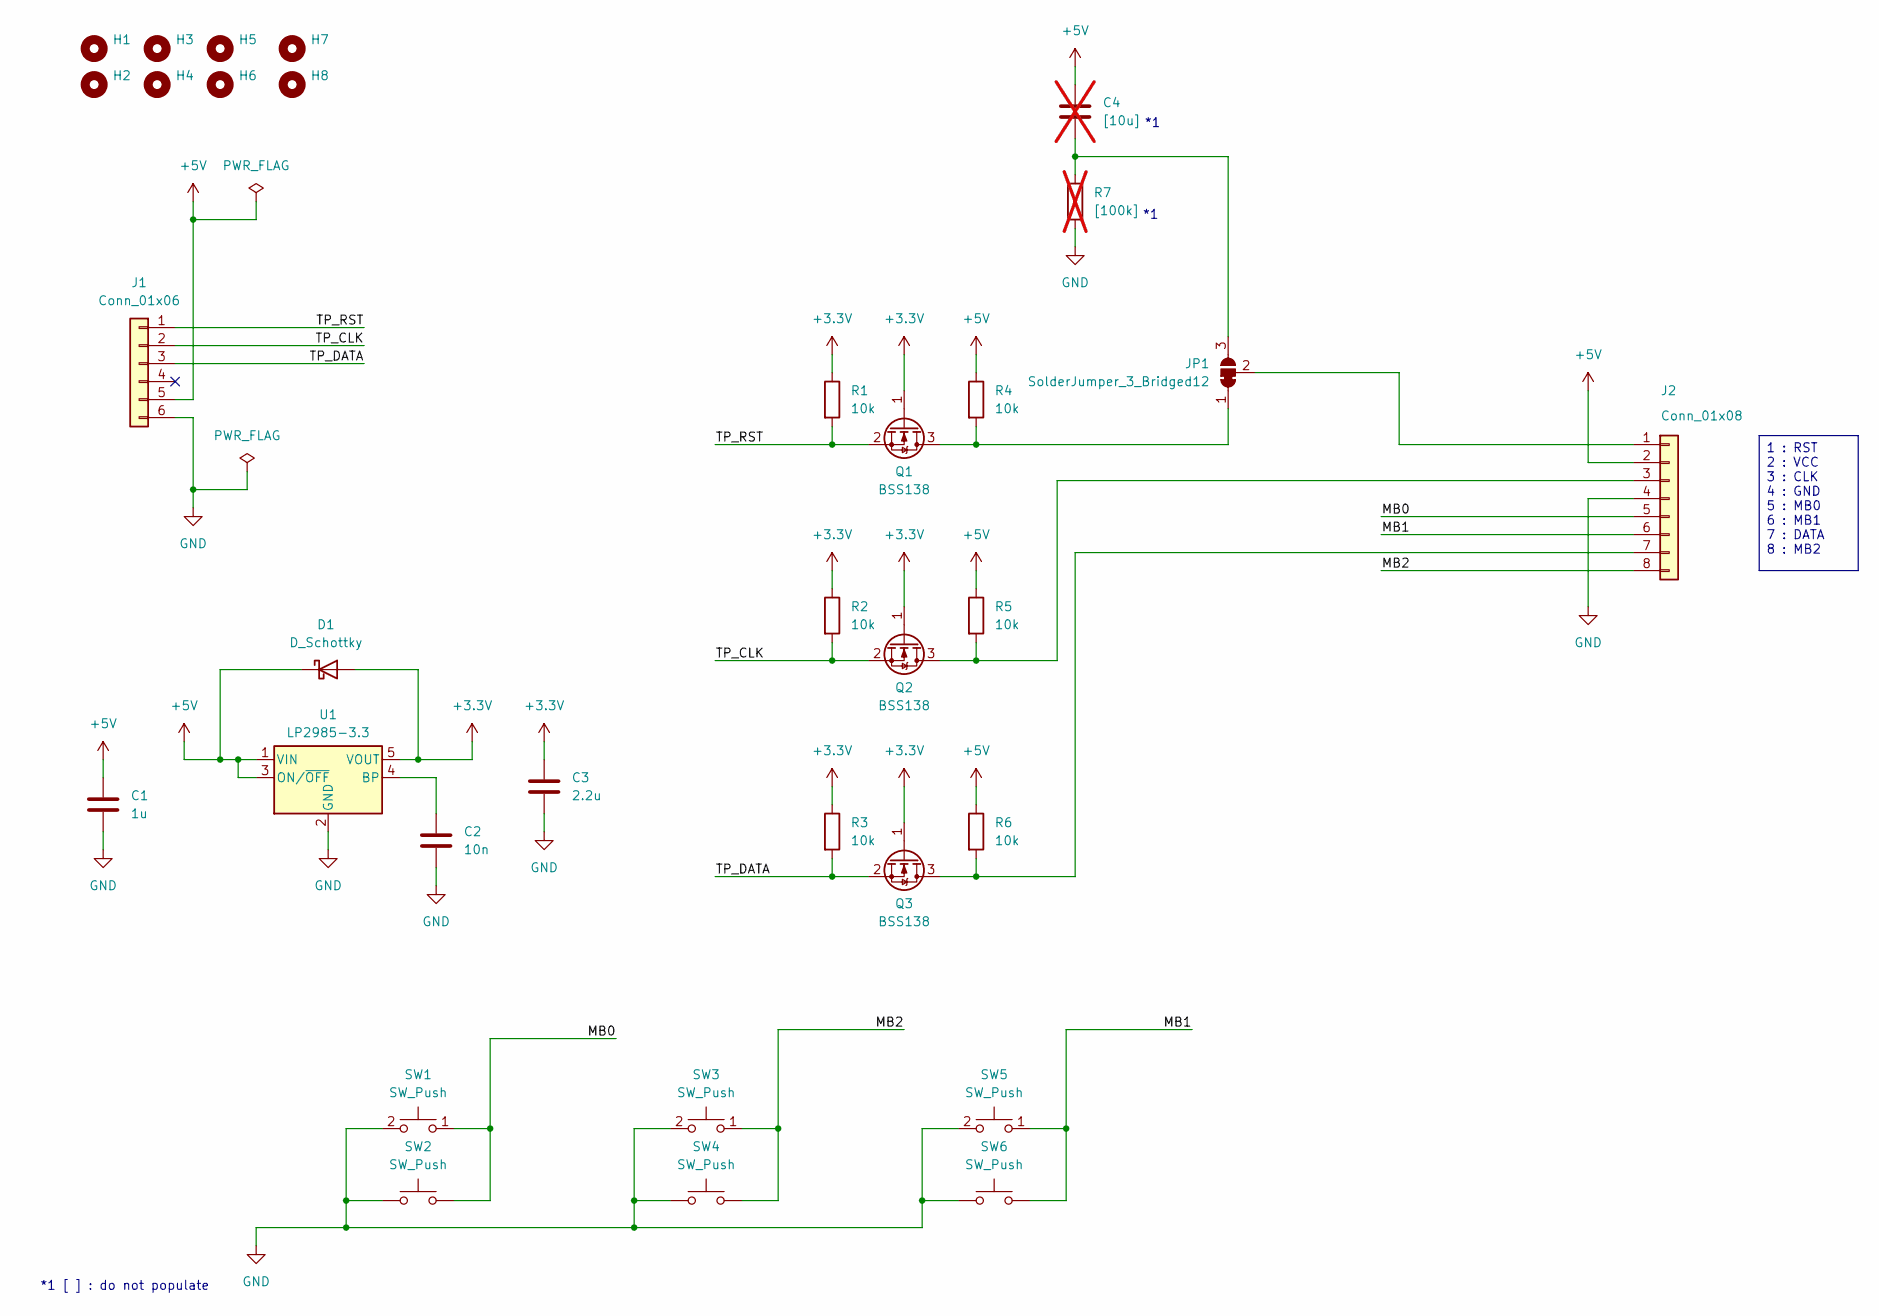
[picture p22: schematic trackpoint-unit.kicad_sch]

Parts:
C1: 1u; C_0603_1608Metric
C2: 10n; C_0603_1608Metric
C3: 2.2u; C_0603_1608Metric
C4: [10u]; C_0603_1608Metric; not fitted
D1: D_Schottky; D_SOD-123
H1, H2, H3, H4, H5, H6, H7, H8: MountingHole; MountingHole_2.2mm_M2
J1: Conn_01x06; JST_PH_S6B-PH-K_1x06_P2.00mm_Horizontal
J2: Conn_01x08; JST_PH_S8B-PH-K_1x08_P2.00mm_Horizontal
JP1: SolderJumper_3_Bridged12; SolderJumper-3_P1.3mm_Bridged12_RoundedPad1.0x1.5mm
Q1, Q2, Q3: BSS138; SOT-23
R1, R2, R3, R4, R5, R6: 10k; R_0603_1608Metric
R7: [100k]; R_0603_1608Metric; not fitted
SW1, SW3, SW5: SW_Push; SW_Hotswap_Kailh_MX
SW2, SW4, SW6: SW_Push; SW_Hotswap_Kailh_Choc_V1V2_no_mp
U1: LP2985-3.3; SOT-23-5

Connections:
+3.3V: C3.1, D1.2 (A), Q1.1 (G), Q2.1 (G), Q3.1 (G), R1.1, R2.1, R3.1, U1.5 (VOUT)
+5V: C1.1, C4.1, D1.1 (K), J1.5, J2.2, R4.1, R5.1, R6.1, U1.1 (VIN), U1.3 (ON/~OFF)
/MB0: J2.5, SW1.1, SW2.2
/MB1: J2.6, SW5.1, SW6.2
/MB2: J2.8, SW3.1, SW4.2
/TP_CLK: J1.2, Q2.2 (S), R2.2
/TP_DATA: J1.3, Q3.2 (S), R3.2
/TP_RST: J1.1, Q1.2 (S), R1.2
GND: C1.2, C2.2, C3.2, J1.6, J2.4, R7.2, SW1.2, SW2.1, SW3.2, SW4.1, SW5.2, SW6.1, U1.2 (GND)
unnamed: J2.1, JP1.2 (C)
unnamed: J2.3, Q2.3 (D), R5.2
unnamed: J2.7, Q3.3 (D), R6.2
unnamed: JP1.1 (A), Q1.3 (D), R4.2
unnamed: C4.2, JP1.3 (B), R7.1
unnamed: C2.1, U1.4 (BP)

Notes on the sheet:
*1 [ ] : do not populate
1 : RST 2 : VCC 3 : CLK 4 : GND 5 : MB0 6 : MB1 7 : DATA 8 : MB2

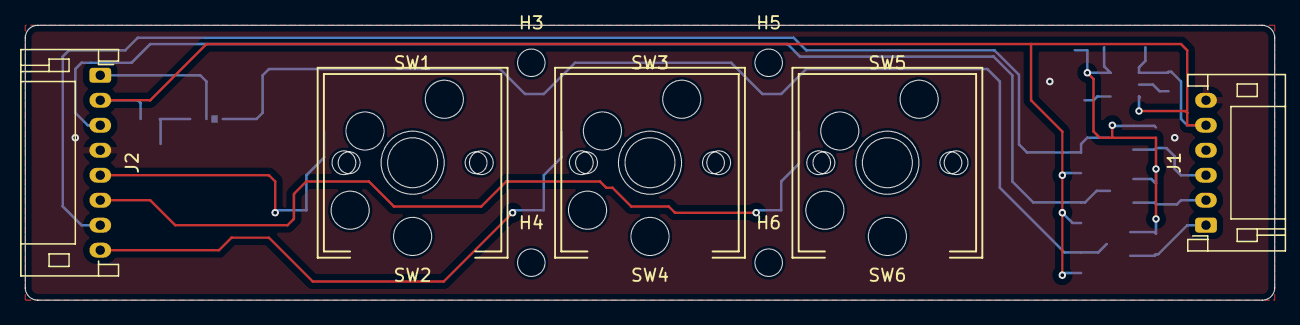
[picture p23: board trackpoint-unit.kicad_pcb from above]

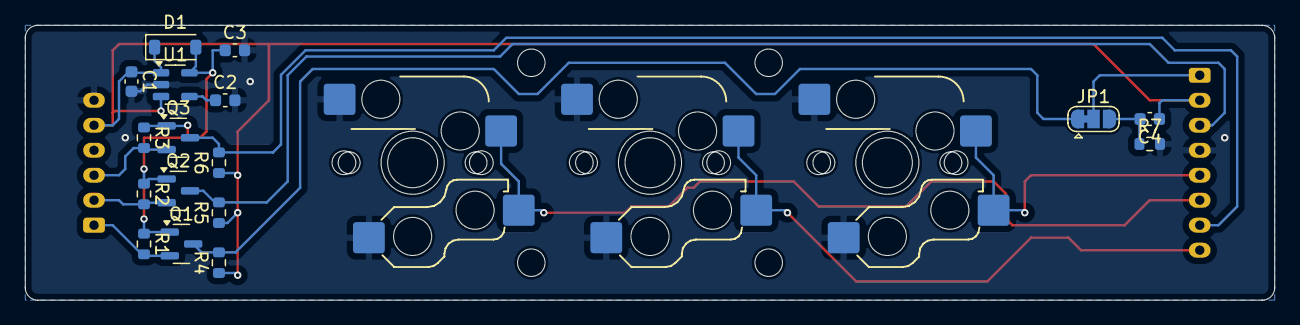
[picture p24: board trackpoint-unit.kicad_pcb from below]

Board: 2 copper layers, 100.0 x 22.0 mm, 33 parts (17 on the bottom side), 15 nets.

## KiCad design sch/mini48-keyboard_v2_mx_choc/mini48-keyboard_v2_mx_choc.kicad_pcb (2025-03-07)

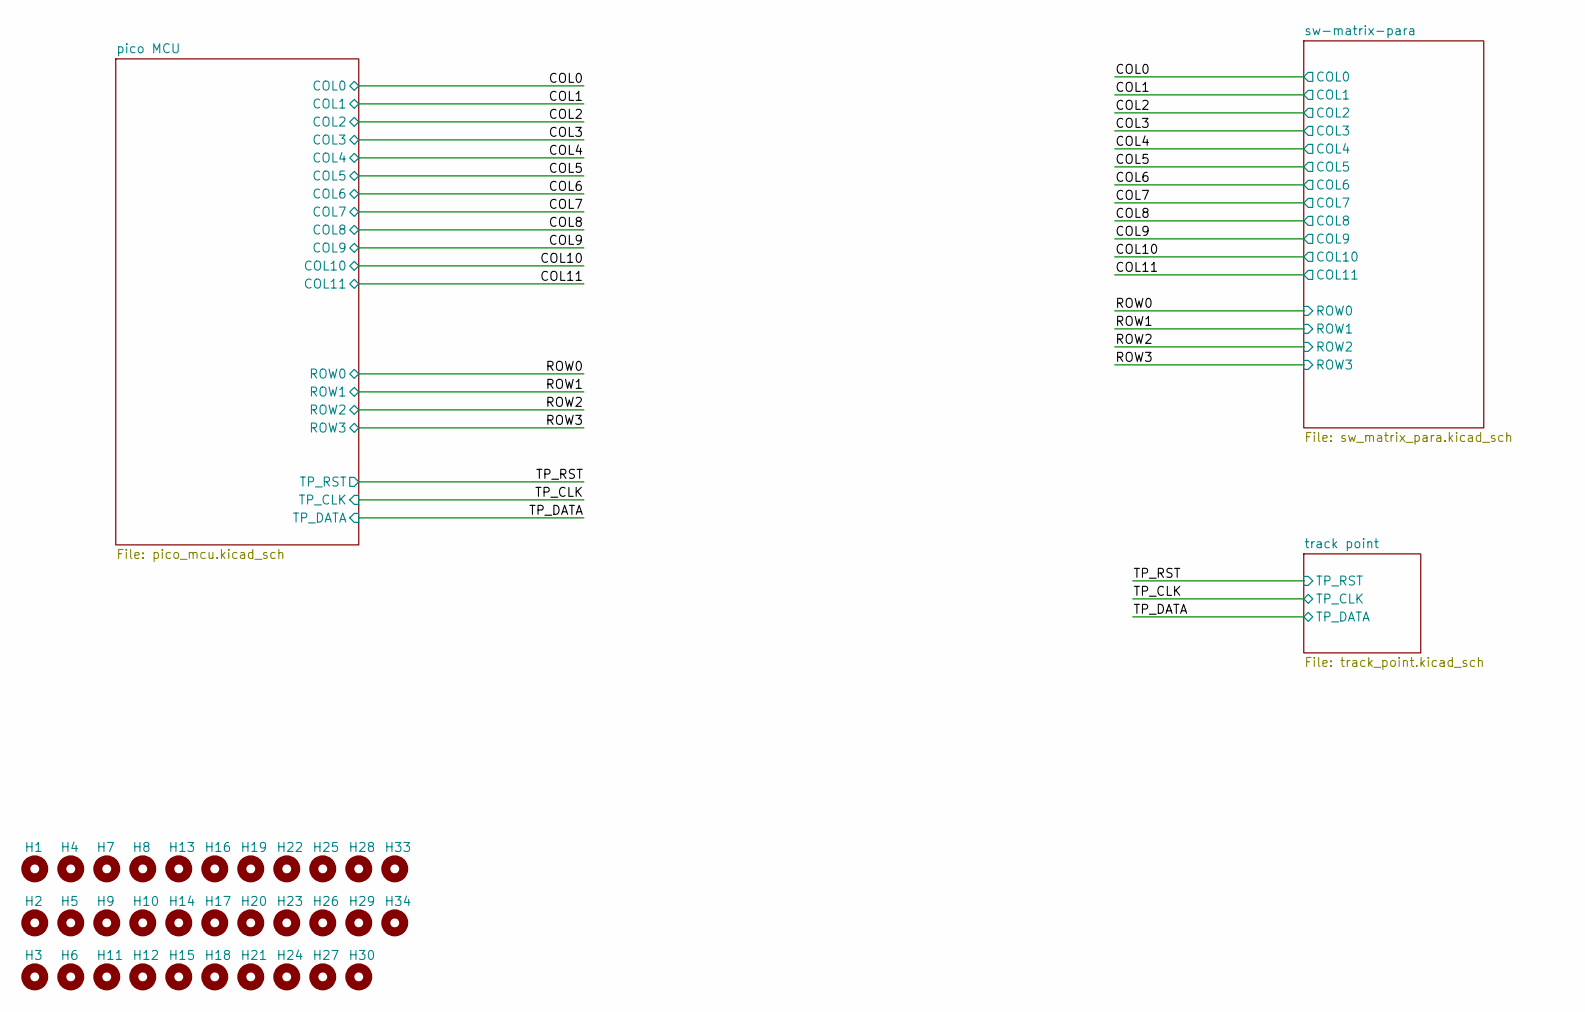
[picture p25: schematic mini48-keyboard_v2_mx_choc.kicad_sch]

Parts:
H1, H2, H3, H4, H5, H6, H7, H8, H9, H10, H11, H12, H13, H14, H15, H16, H17, H18, H19, H20, H21, H22, H23, H24, H25, H26, H27, H28, H29, H30, H33, H34: MountingHole; my_MountingHole_3.2mm_M3

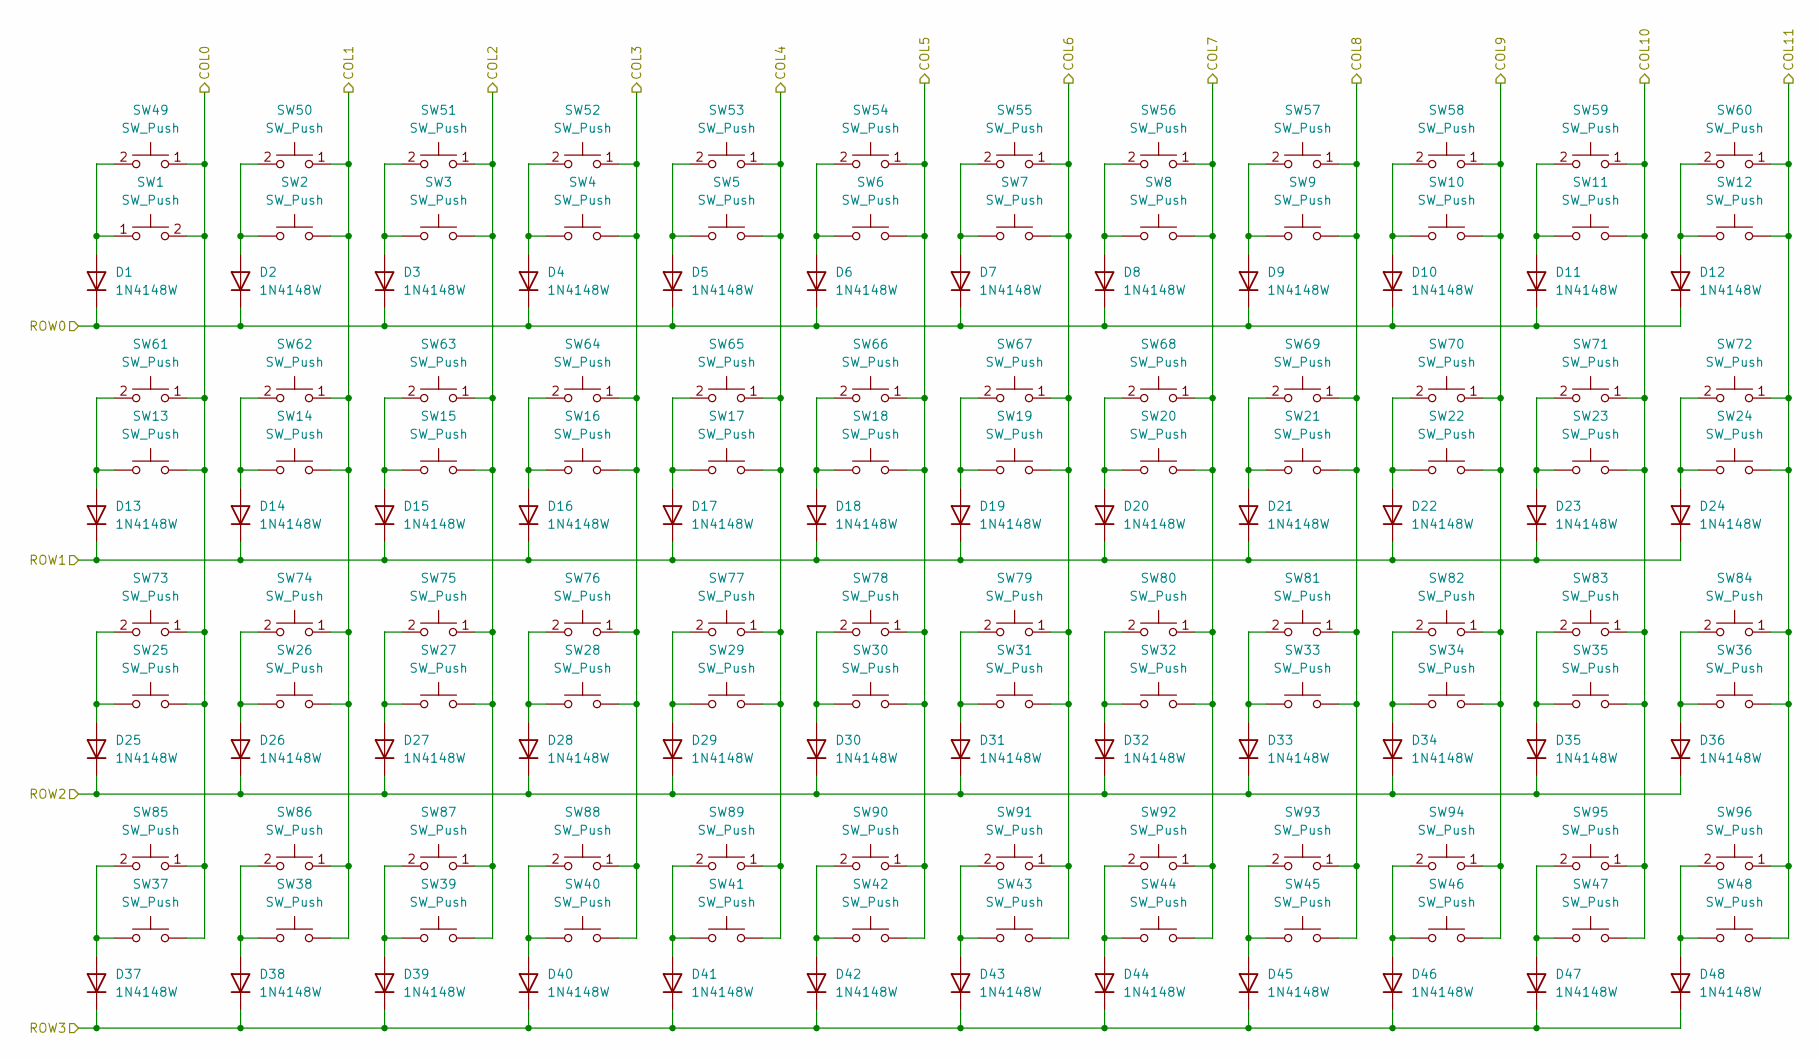
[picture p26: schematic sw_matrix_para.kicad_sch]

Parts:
D1, D2, D3, D4, D5, D6, D7, D8, D9, D10, D11, D12, D13, D14, D15, D16, D17, D18, D19, D20, D21, D22, D23, D24, D25, D26, D27, D28, D29, D30, D31, D32, D33, D34, D35, D36, D37, D38, D39, D40, D41, D42, D43, D44, D45, D46, D47, D48: 1N4148W; D_SOD-123
SW1, SW2, SW3, SW4, SW5, SW6, SW7, SW8, SW9, SW10, SW11, SW12, SW13, SW14, SW15, SW16, SW17, SW18, SW19, SW20, SW21, SW22, SW23, SW24, SW25, SW26, SW27, SW28, SW29, SW30, SW31, SW32, SW33, SW34, SW35, SW36, SW37, SW38, SW39, SW40, SW41, SW42, SW43, SW44, SW45, SW46, SW47, SW48: SW_Push; SW_Hotswap_Kailh_Choc_V1V2_no_mp
SW49, SW50, SW51, SW52, SW53, SW54, SW55, SW56, SW57, SW58, SW59, SW60, SW61, SW62, SW63, SW64, SW65, SW66, SW67, SW68, SW69, SW70, SW71, SW72, SW73, SW74, SW75, SW76, SW77, SW78, SW79, SW80, SW81, SW82, SW83, SW84, SW85, SW86, SW87, SW88, SW89, SW90, SW91, SW92, SW93, SW94, SW95, SW96: SW_Push; SW_Hotswap_Kailh_MX

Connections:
/COL0: SW1.2, SW13.2, SW25.2, SW37.2, SW49.1, SW61.1, SW73.1, SW85.1; also elsewhere on the board
/COL1: SW2.2, SW14.2, SW26.2, SW38.2, SW50.1, SW62.1, SW74.1, SW86.1; also elsewhere on the board
/COL2: SW3.2, SW15.2, SW27.2, SW39.2, SW51.1, SW63.1, SW75.1, SW87.1; also elsewhere on the board
/COL3: SW4.2, SW16.2, SW28.2, SW40.2, SW52.1, SW64.1, SW76.1, SW88.1; also elsewhere on the board
/COL4: SW5.2, SW17.2, SW29.2, SW41.2, SW53.1, SW65.1, SW77.1, SW89.1; also elsewhere on the board
/COL5: SW6.2, SW18.2, SW30.2, SW42.2, SW54.1, SW66.1, SW78.1, SW90.1; also elsewhere on the board
/COL6: SW7.2, SW19.2, SW31.2, SW43.2, SW55.1, SW67.1, SW79.1, SW91.1; also elsewhere on the board
/COL7: SW8.2, SW20.2, SW32.2, SW44.2, SW56.1, SW68.1, SW80.1, SW92.1; also elsewhere on the board
/COL8: SW9.2, SW21.2, SW33.2, SW45.2, SW57.1, SW69.1, SW81.1, SW93.1; also elsewhere on the board
/COL9: SW10.2, SW22.2, SW34.2, SW46.2, SW58.1, SW70.1, SW82.1, SW94.1; also elsewhere on the board
/COL10: SW11.2, SW23.2, SW35.2, SW47.2, SW59.1, SW71.1, SW83.1, SW95.1; also elsewhere on the board
/COL11: SW12.2, SW24.2, SW36.2, SW48.2, SW60.1, SW72.1, SW84.1, SW96.1; also elsewhere on the board
/ROW0: D1.1 (K), D2.1 (K), D3.1 (K), D4.1 (K), D5.1 (K), D6.1 (K), D7.1 (K), D8.1 (K), D9.1 (K), D10.1 (K), D11.1 (K), D12.1 (K); also elsewhere on the board
/ROW1: D13.1 (K), D14.1 (K), D15.1 (K), D16.1 (K), D17.1 (K), D18.1 (K), D19.1 (K), D20.1 (K), D21.1 (K), D22.1 (K), D23.1 (K), D24.1 (K); also elsewhere on the board
/ROW2: D25.1 (K), D26.1 (K), D27.1 (K), D28.1 (K), D29.1 (K), D30.1 (K), D31.1 (K), D32.1 (K), D33.1 (K), D34.1 (K), D35.1 (K), D36.1 (K); also elsewhere on the board
/ROW3: D37.1 (K), D38.1 (K), D39.1 (K), D40.1 (K), D41.1 (K), D42.1 (K), D43.1 (K), D44.1 (K), D45.1 (K), D46.1 (K), D47.1 (K), D48.1 (K); also elsewhere on the board
unnamed: D1.2 (A), SW1.1, SW49.2
unnamed: D2.2 (A), SW2.1, SW50.2
unnamed: D3.2 (A), SW3.1, SW51.2
unnamed: D4.2 (A), SW4.1, SW52.2
unnamed: D5.2 (A), SW5.1, SW53.2
unnamed: D6.2 (A), SW6.1, SW54.2
unnamed: D7.2 (A), SW7.1, SW55.2
unnamed: D8.2 (A), SW8.1, SW56.2
unnamed: D9.2 (A), SW9.1, SW57.2
unnamed: D10.2 (A), SW10.1, SW58.2
unnamed: D11.2 (A), SW11.1, SW59.2
unnamed: D12.2 (A), SW12.1, SW60.2
unnamed: D13.2 (A), SW13.1, SW61.2
unnamed: D14.2 (A), SW14.1, SW62.2
unnamed: D15.2 (A), SW15.1, SW63.2
unnamed: D16.2 (A), SW16.1, SW64.2
unnamed: D17.2 (A), SW17.1, SW65.2
unnamed: D18.2 (A), SW18.1, SW66.2
unnamed: D19.2 (A), SW19.1, SW67.2
unnamed: D20.2 (A), SW20.1, SW68.2
unnamed: D21.2 (A), SW21.1, SW69.2
unnamed: D22.2 (A), SW22.1, SW70.2
unnamed: D23.2 (A), SW23.1, SW71.2
unnamed: D24.2 (A), SW24.1, SW72.2
unnamed: D25.2 (A), SW25.1, SW73.2
unnamed: D26.2 (A), SW26.1, SW74.2
unnamed: D27.2 (A), SW27.1, SW75.2
unnamed: D28.2 (A), SW28.1, SW76.2
unnamed: D29.2 (A), SW29.1, SW77.2
unnamed: D30.2 (A), SW30.1, SW78.2
unnamed: D31.2 (A), SW31.1, SW79.2
unnamed: D32.2 (A), SW32.1, SW80.2
unnamed: D33.2 (A), SW33.1, SW81.2
unnamed: D34.2 (A), SW34.1, SW82.2
unnamed: D35.2 (A), SW35.1, SW83.2
unnamed: D36.2 (A), SW36.1, SW84.2
unnamed: D37.2 (A), SW37.1, SW85.2
unnamed: D38.2 (A), SW38.1, SW86.2
unnamed: D39.2 (A), SW39.1, SW87.2
unnamed: D40.2 (A), SW40.1, SW88.2
unnamed: D41.2 (A), SW41.1, SW89.2
unnamed: D42.2 (A), SW42.1, SW90.2
unnamed: D43.2 (A), SW43.1, SW91.2
unnamed: D44.2 (A), SW44.1, SW92.2
unnamed: D45.2 (A), SW45.1, SW93.2
unnamed: D46.2 (A), SW46.1, SW94.2
unnamed: D47.2 (A), SW47.1, SW95.2
unnamed: D48.2 (A), SW48.1, SW96.2

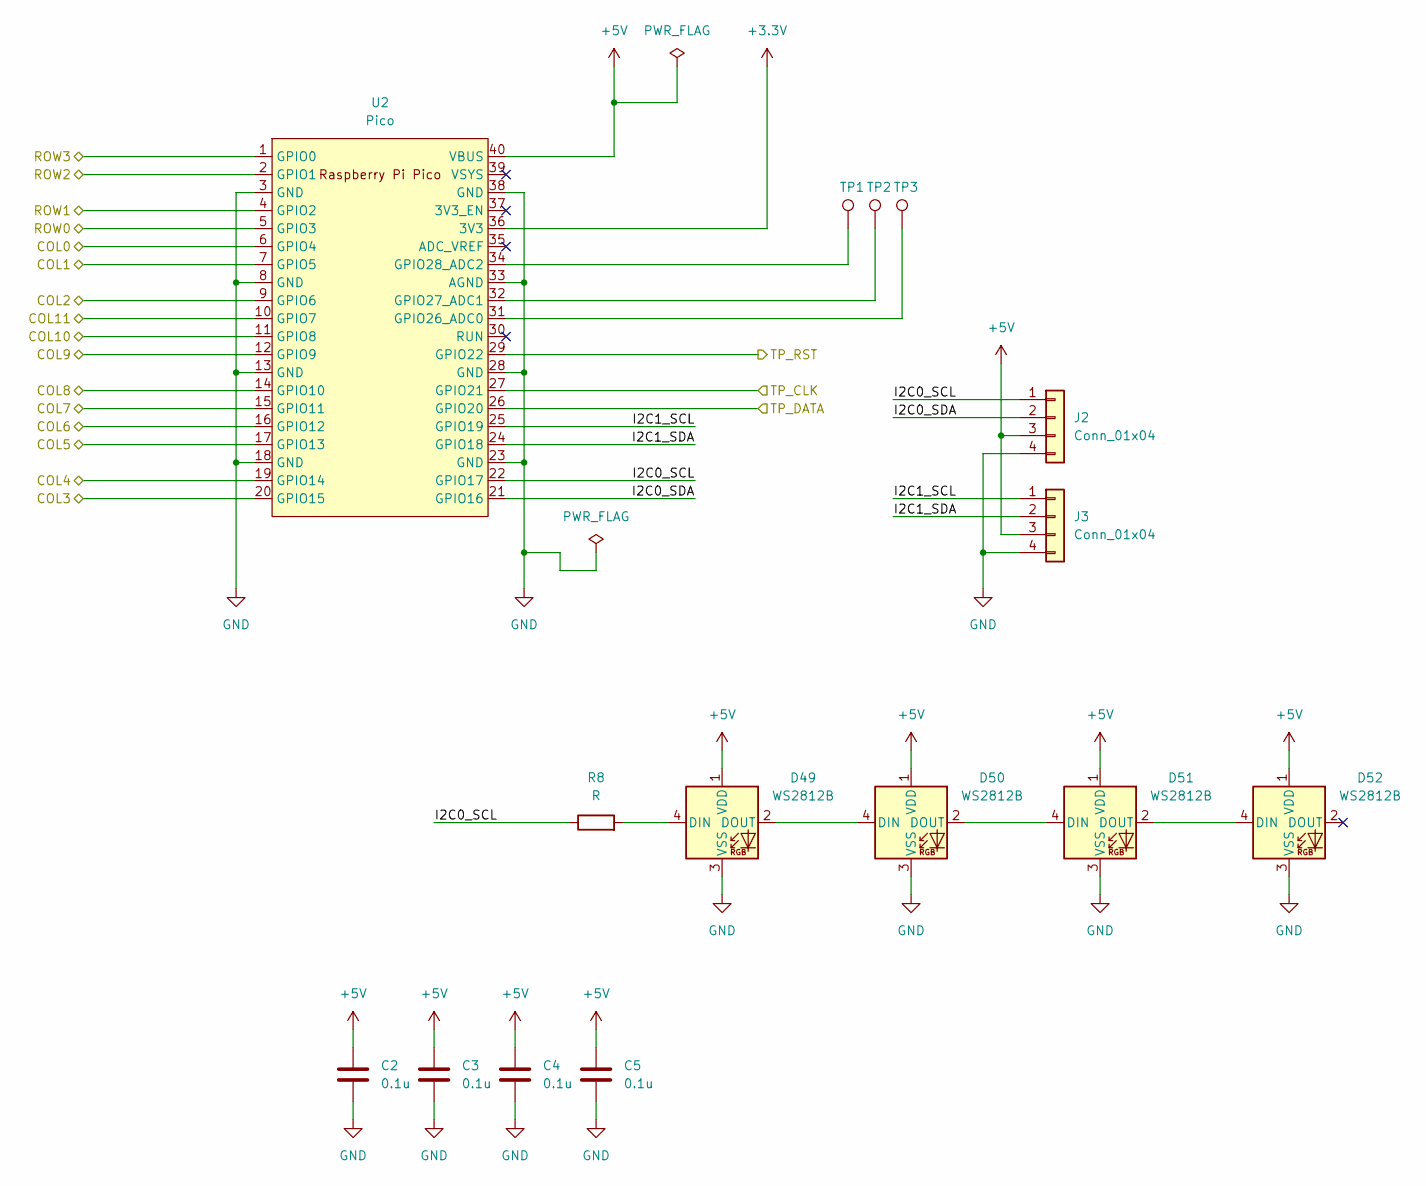
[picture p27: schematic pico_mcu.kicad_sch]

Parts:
C2, C3, C4, C5: 0.1u; C_0603_1608Metric
D49, D50, D51, D52: WS2812B; LED_WS2812B_PLCC4_5.0x5.0mm_P3.2mm
J2, J3: Conn_01x04; JST_PH_S4B-PH-K_1x04_P2.00mm_Horizontal
R8: R; R_0603_1608Metric
TP1, TP2, TP3: TestPoint; TestPoint_Pad_D1.0mm
U2: Pico; pico_no_dbg_th_p0.85

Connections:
+3.3V: U2.36 (3V3); also elsewhere on the board
+5V: C2.1, C3.1, C4.1, C5.1, D49.1 (VDD), D50.1 (VDD), D51.1 (VDD), D52.1 (VDD), J2.3, J3.3, U2.40 (VBUS); also elsewhere on the board
/COL0: U2.6 (GPIO4); also elsewhere on the board
/COL1: U2.7 (GPIO5); also elsewhere on the board
/COL2: U2.9 (GPIO6); also elsewhere on the board
/COL3: U2.20 (GPIO15); also elsewhere on the board
/COL4: U2.19 (GPIO14); also elsewhere on the board
/COL5: U2.17 (GPIO13); also elsewhere on the board
/COL6: U2.16 (GPIO12); also elsewhere on the board
/COL7: U2.15 (GPIO11); also elsewhere on the board
/COL8: U2.14 (GPIO10); also elsewhere on the board
/COL9: U2.12 (GPIO9); also elsewhere on the board
/COL10: U2.11 (GPIO8); also elsewhere on the board
/COL11: U2.10 (GPIO7); also elsewhere on the board
/ROW0: U2.5 (GPIO3); also elsewhere on the board
/ROW1: U2.4 (GPIO2); also elsewhere on the board
/ROW2: U2.2 (GPIO1); also elsewhere on the board
/ROW3: U2.1 (GPIO0); also elsewhere on the board
/TP_CLK: U2.27 (GPIO21); also elsewhere on the board
/TP_DATA: U2.26 (GPIO20); also elsewhere on the board
/TP_RST: U2.29 (GPIO22); also elsewhere on the board
/pico MCU/I2C0_SCL: J2.1, R8.1, U2.22 (GPIO17)
/pico MCU/I2C0_SDA: J2.2, U2.21 (GPIO16)
/pico MCU/I2C1_SCL: J3.1, U2.25 (GPIO19)
/pico MCU/I2C1_SDA: J3.2, U2.24 (GPIO18)
GND: C2.2, C3.2, C4.2, C5.2, D49.3 (VSS), D50.3 (VSS), D51.3 (VSS), D52.3 (VSS), J2.4, J3.4, U2.3 (GND), U2.8 (GND), U2.13 (GND), U2.18 (GND), U2.23 (GND), U2.28 (GND), U2.33 (AGND), U2.38 (GND); also elsewhere on the board
unnamed: D49.4 (DIN), R8.2
unnamed: D49.2 (DOUT), D50.4 (DIN)
unnamed: D50.2 (DOUT), D51.4 (DIN)
unnamed: D51.2 (DOUT), D52.4 (DIN)
unnamed: TP3.1, U2.31 (GPIO26_ADC0)
unnamed: TP2.1, U2.32 (GPIO27_ADC1)
unnamed: TP1.1, U2.34 (GPIO28_ADC2)

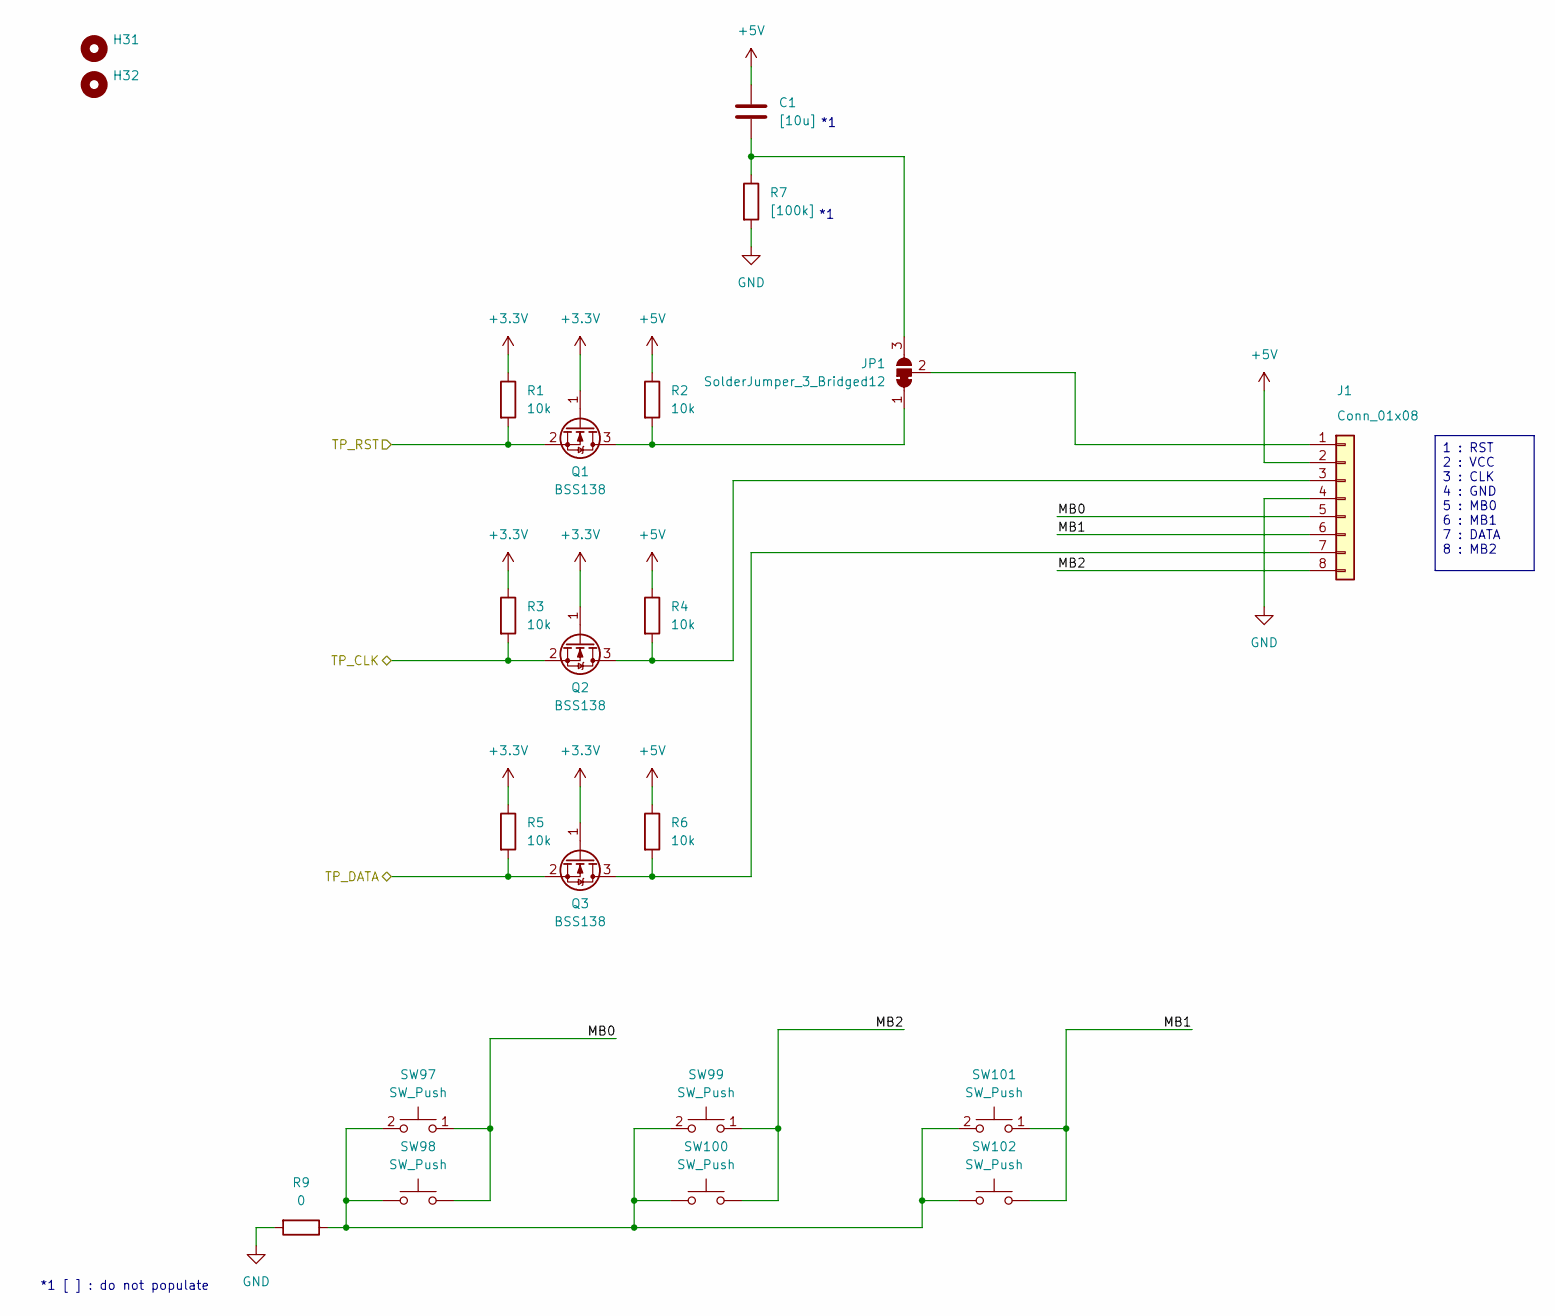
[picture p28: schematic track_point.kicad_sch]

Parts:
C1: [10u]; C_0603_1608Metric
H31, H32: MountingHole; MountingHole_2.2mm_M2
J1: Conn_01x08; JST_PH_B8B-PH-K_1x08_P2.00mm_Vertical
JP1: SolderJumper_3_Bridged12; SolderJumper-3_P1.3mm_Bridged12_RoundedPad1.0x1.5mm
Q1, Q2, Q3: BSS138; SOT-23
R1, R2, R3, R4, R5, R6: 10k; R_0603_1608Metric
R7: [100k]; R_0603_1608Metric
R9: 0; R_0603_1608Metric
SW97, SW99, SW101: SW_Push; SW_Hotswap_Kailh_MX
SW98, SW100, SW102: SW_Push; SW_Hotswap_Kailh_Choc_V1V2_no_mp

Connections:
+3.3V: Q1.1 (G), Q2.1 (G), Q3.1 (G), R1.1, R3.1, R5.1; also elsewhere on the board
+5V: C1.1, J1.2, R2.1, R4.1, R6.1; also elsewhere on the board
/TP_CLK: Q2.2 (S), R3.2; also elsewhere on the board
/TP_DATA: Q3.2 (S), R5.2; also elsewhere on the board
/TP_RST: Q1.2 (S), R1.2; also elsewhere on the board
/track point/MB0: J1.5, SW97.1, SW98.2
/track point/MB1: J1.6, SW101.1, SW102.2
/track point/MB2: J1.8, SW99.1, SW100.2
GND: J1.4, R7.2, R9.2; also elsewhere on the board
unnamed: J1.1, JP1.2 (C)
unnamed: J1.3, Q2.3 (D), R4.2
unnamed: J1.7, Q3.3 (D), R6.2
unnamed: JP1.1 (A), Q1.3 (D), R2.2
unnamed: C1.2, JP1.3 (B), R7.1
unnamed: R9.1, SW97.2, SW98.1, SW99.2, SW100.1, SW101.2, SW102.1

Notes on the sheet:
*1 [ ] : do not populate
1 : RST 2 : VCC 3 : CLK 4 : GND 5 : MB0 6 : MB1 7 : DATA 8 : MB2

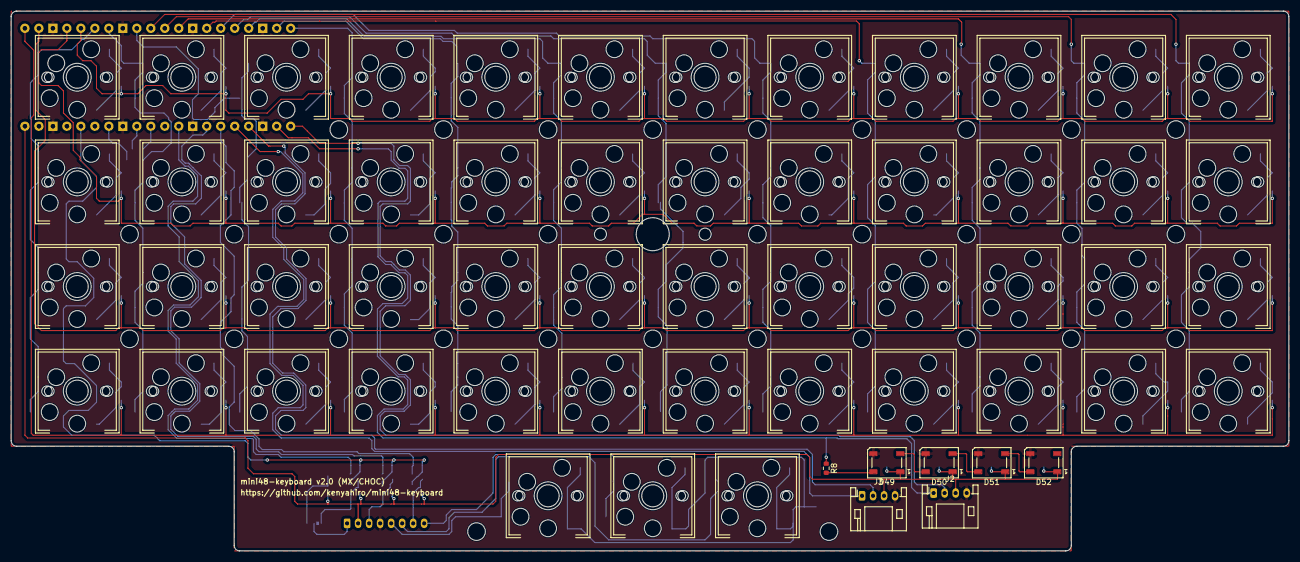
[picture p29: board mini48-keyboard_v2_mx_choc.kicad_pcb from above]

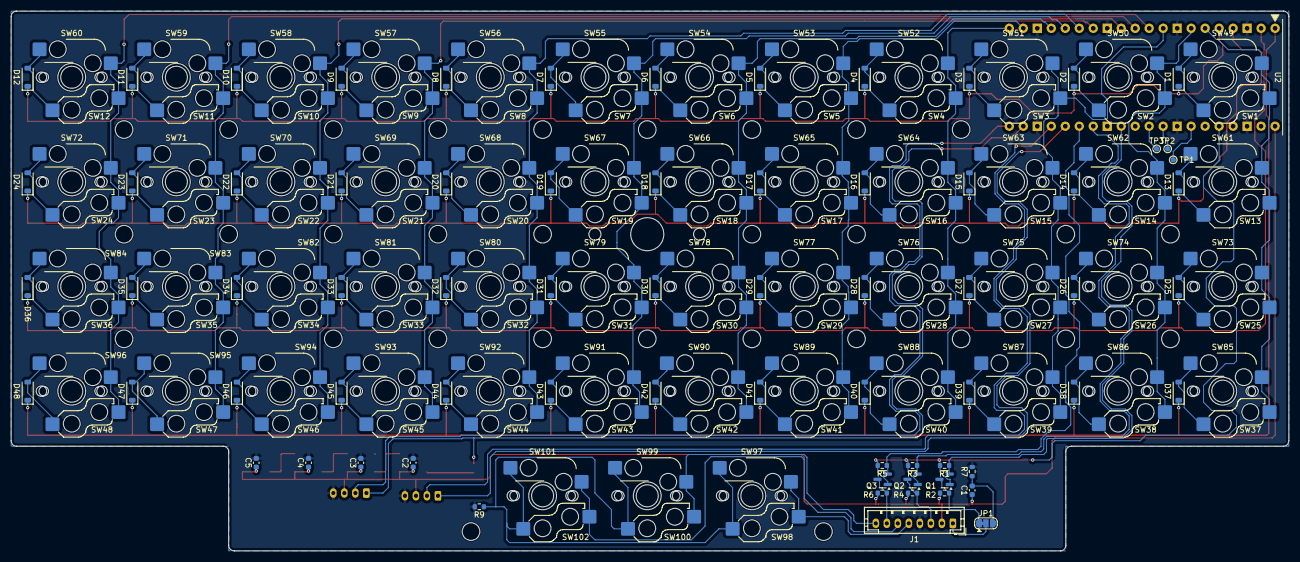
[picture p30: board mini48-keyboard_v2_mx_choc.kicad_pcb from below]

Board: 2 copper layers, 232.0 x 98.0 mm, 213 parts (70 on the bottom side), 90 nets.

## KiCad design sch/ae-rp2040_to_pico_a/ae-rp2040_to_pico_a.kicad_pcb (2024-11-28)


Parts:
D1: CUHS20S30; D_SOD-323_HandSoldering
H1, H2, H3, H4: MountingHole; MountingHole_3.2mm_M3
J1: 5077CR-16SMC2-BK-TR; NELTRON_5077CR-16SMC2-BK-TR; PARTREV B
JP1, JP2: SolderJumper_2_Bridged; SolderJumper-2_P1.3mm_Bridged_Pad1.0x1.5mm
R1, R2: 5.1k; R_0603_1608Metric
TP1, TP2: TestPoint; TestPoint_Pad_D1.0mm
U1: AE-RP2040
U2: Pico; pico_no_dbg_smd_th_p0.85

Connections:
/CC1: J1.A5 (CC1), R2.1
/CC2: J1.B5 (CC2), R1.1
/GPIO0: U1.2 (GPIO0), U2.1 (GPIO0)
/GPIO1: U1.3 (GPIO1), U2.2 (GPIO1)
/GPIO2: U1.4 (GPIO2), U2.4 (GPIO2)
/GPIO3: U1.5 (GPIO3), U2.5 (GPIO3)
/GPIO4: U1.6 (GPIO4), U2.6 (GPIO4)
/GPIO5: U1.7 (GPIO5), U2.7 (GPIO5)
/GPIO6: U1.8 (GPIO6), U2.9 (GPIO6)
/GPIO7: U1.9 (GPIO7), U2.10 (GPIO7)
/GPIO8: U1.10 (GPIO8), U2.11 (GPIO8)
/GPIO9: U1.11 (GPIO9), U2.12 (GPIO9)
/GPIO10: U1.12 (GPIO10), U2.14 (GPIO10)
/GPIO11: U1.13 (GPIO11), U2.15 (GPIO11)
/GPIO12: U1.14 (GPIO12), U2.16 (GPIO12)
/GPIO13: U1.15 (GPIO13), U2.17 (GPIO13)
/GPIO14: U1.16 (GPIO14), U2.19 (GPIO14)
/GPIO15: U1.17 (GPIO15), U2.20 (GPIO15)
/GPIO16: U1.19 (GPIO16), U2.21 (GPIO16)
/GPIO17: U1.20 (GPIO17), U2.22 (GPIO17)
/GPIO18: U1.21 (GPIO18), U2.24 (GPIO18)
/GPIO19: U1.22 (GPIO19), U2.25 (GPIO19)
/GPIO20: U1.23 (GPIO20), U2.26 (GPIO20)
/GPIO21: U1.24 (GPIO21), U2.27 (GPIO21)
/GPIO22: U1.25 (GPIO22), U2.29 (GPIO22)
/GPIO26: U1.29 (GPIO26), U2.31 (GPIO26_ADC0)
/GPIO27: U1.30 (GPIO27), U2.32 (GPIO27_ADC1)
/GPIO28: U1.31 (GPIO28), U2.34 (GPIO28_ADC2)
/P3: JP2.2 (B), U2.36 (3V3)
/P5: D1.1 (K), JP1.1 (A), U2.39 (VSYS)
/USBC_DN: J1.A7 (DN1), J1.B7 (DN2), TP1.1
/USBC_DP: J1.A6 (DP1), J1.B6 (DP2), TP2.1
GND: J1.A1_B12 (GND), J1.B1_A12 (GND), J1.S1 (SHIELD), J1.S2 (SHIELD), J1.S3 (SHIELD), J1.S4 (SHIELD), R1.2, R2.2, U1.18 (GND), U1.33 (GND), U2.3 (GND), U2.8 (GND), U2.13 (GND), U2.18 (GND), U2.23 (GND), U2.28 (GND), U2.33 (AGND), U2.38 (GND)
unnamed: D1.2 (A), J1.A4_B9 (VBUS), J1.B4_A9 (VBUS)
unnamed: JP1.2 (B), U1.1 (+5V)
unnamed: JP2.1 (A), U1.34 (+3.3V)



Board: 2 copper layers, 64.0 x 54.5 mm, 14 parts (3 on the bottom side), 36 nets.

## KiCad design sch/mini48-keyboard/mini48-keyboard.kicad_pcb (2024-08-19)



Board: 2 copper layers, 232.0 x 76.0 mm, 97 parts (49 on the bottom side), 65 nets.

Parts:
D1, D2, D3, D4, D5, D6, D7, D8, D9, D10, D11, D12, D13, D14, D15, D16, D17, D18, D19, D20, D21, D22, D23, D24, D25, D26, D27, D28, D29, D30, D31, D32, D33, D34, D35, D36, D37, D38, D39, D40, D41, D42, D43, D44, D45, D46, D47, D48: 1N4148W; D_SOD-123
SW1, SW2, SW3, SW4, SW5, SW6, SW7, SW8, SW9, SW10, SW11, SW12, SW13, SW14, SW15, SW16, SW17, SW18, SW19, SW20, SW21, SW22, SW23, SW24, SW25, SW26, SW27, SW28, SW29, SW30, SW31, SW32, SW33, SW34, SW35, SW36, SW37, SW38, SW39, SW40, SW41, SW42, SW43, SW44, SW45, SW46, SW47, SW48: SW_Push; my_Kailh_socket_PG1350
U1: AE-RP2040

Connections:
/COL0: SW1.2, SW13.2, SW25.2, SW37.2, U1.17 (GPIO15)
/COL1: SW2.2, SW14.2, SW26.2, SW38.2, U1.16 (GPIO14)
/COL2: SW3.2, SW15.2, SW27.2, SW39.2, U1.15 (GPIO13)
/COL3: SW4.2, SW16.2, SW28.2, SW40.2, U1.14 (GPIO12)
/COL4: SW5.2, SW17.2, SW29.2, SW41.2, U1.13 (GPIO11)
/COL5: SW6.2, SW18.2, SW30.2, SW42.2, U1.12 (GPIO10)
/COL6: SW7.2, SW19.2, SW31.2, SW43.2, U1.19 (GPIO16)
/COL7: SW8.2, SW20.2, SW32.2, SW44.2, U1.20 (GPIO17)
/COL8: SW9.2, SW21.2, SW33.2, SW45.2, U1.21 (GPIO18)
/COL9: SW10.2, SW22.2, SW34.2, SW46.2, U1.22 (GPIO19)
/COL10: SW11.2, SW23.2, SW35.2, SW47.2, U1.23 (GPIO20)
/COL11: SW12.2, SW24.2, SW36.2, SW48.2, U1.24 (GPIO21)
/ROW0: D1.1 (K), D2.1 (K), D3.1 (K), D4.1 (K), D5.1 (K), D6.1 (K), D7.1 (K), D8.1 (K), D9.1 (K), D10.1 (K), D11.1 (K), D12.1 (K), U1.4 (GPIO2)
/ROW1: D13.1 (K), D14.1 (K), D15.1 (K), D16.1 (K), D17.1 (K), D18.1 (K), D19.1 (K), D20.1 (K), D21.1 (K), D22.1 (K), D23.1 (K), D24.1 (K), U1.5 (GPIO3)
/ROW2: D25.1 (K), D26.1 (K), D27.1 (K), D28.1 (K), D29.1 (K), D30.1 (K), D31.1 (K), D32.1 (K), D33.1 (K), D34.1 (K), D35.1 (K), D36.1 (K), U1.6 (GPIO4)
/ROW3: D37.1 (K), D38.1 (K), D39.1 (K), D40.1 (K), D41.1 (K), D42.1 (K), D43.1 (K), D44.1 (K), D45.1 (K), D46.1 (K), D47.1 (K), D48.1 (K), U1.7 (GPIO5)
GND: U1.18 (GND), U1.33 (GND)
unnamed: D1.2 (A), SW1.1
unnamed: D2.2 (A), SW2.1
unnamed: D3.2 (A), SW3.1
unnamed: D4.2 (A), SW4.1
unnamed: D5.2 (A), SW5.1
unnamed: D6.2 (A), SW6.1
unnamed: D7.2 (A), SW7.1
unnamed: D8.2 (A), SW8.1
unnamed: D9.2 (A), SW9.1
unnamed: D10.2 (A), SW10.1
unnamed: D11.2 (A), SW11.1
unnamed: D12.2 (A), SW12.1
unnamed: D13.2 (A), SW13.1
unnamed: D14.2 (A), SW14.1
unnamed: D15.2 (A), SW15.1
unnamed: D16.2 (A), SW16.1
unnamed: D17.2 (A), SW17.1
unnamed: D18.2 (A), SW18.1
unnamed: D19.2 (A), SW19.1
unnamed: D20.2 (A), SW20.1
unnamed: D21.2 (A), SW21.1
unnamed: D22.2 (A), SW22.1
unnamed: D23.2 (A), SW23.1
unnamed: D24.2 (A), SW24.1
unnamed: D25.2 (A), SW25.1
unnamed: D26.2 (A), SW26.1
unnamed: D27.2 (A), SW27.1
unnamed: D28.2 (A), SW28.1
unnamed: D29.2 (A), SW29.1
unnamed: D30.2 (A), SW30.1
unnamed: D31.2 (A), SW31.1
unnamed: D32.2 (A), SW32.1
unnamed: D33.2 (A), SW33.1
unnamed: D34.2 (A), SW34.1
unnamed: D35.2 (A), SW35.1
unnamed: D36.2 (A), SW36.1
unnamed: D37.2 (A), SW37.1
unnamed: D38.2 (A), SW38.1
unnamed: D39.2 (A), SW39.1
unnamed: D40.2 (A), SW40.1
unnamed: D41.2 (A), SW41.1
unnamed: D42.2 (A), SW42.1
unnamed: D43.2 (A), SW43.1
unnamed: D44.2 (A), SW44.1
unnamed: D45.2 (A), SW45.1
unnamed: D46.2 (A), SW46.1
unnamed: D47.2 (A), SW47.1
unnamed: D48.2 (A), SW48.1

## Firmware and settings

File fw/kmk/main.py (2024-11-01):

from kb import KMKKeyboard

from kmk.extensions.stringy_keymaps import StringyKeymaps
from kmk.keys import KC
from kmk.modules.layers import Layers

Mini48 = KMKKeyboard()

Mini48.modules.append(Layers())
Mini48.extensions.append(StringyKeymaps())

MOLYR = KC.MO(1)

# Make this for better looking formatting...
______ = 'NO'

# fmt:off
Mini48.keymap = [[
  # Layer 0 QWERTY
  'TAB',  'Q',    'W',    'E',    'R',    'T',    'Y',    'U',    'I',    'O',   'P',    'BSLS',
  'LCTL', 'A',    'S',    'D',    'F',    'G',    'H',    'J',    'K',    'L',   'SCLN', 'ENT',
  'LSFT', 'Z',    'X',    'C',    'V',    'B',    'N',    'M',    'COMM', 'DOT', 'SLSH', 'RSFT',
  'ESC',  'LGUI', 'LALT', MOLYR,  'SPC',  ______, ______, ______, 'LEFT', 'DOWN', 'UP',  'RGHT',
], [
  # Layer 1
  'TAB',  'Q',    'W',    'E',    'R',    'T',    'Y',    'U',    'I',    'O',   'P',    'BSLS',
  'LCTL', 'A',    'S',    'D',    'F',    'G',    'H',    'J',    'K',    'L',   'SCLN', 'ENT',
  'LSFT', 'Z',    'X',    'C',    'V',    'B',    'N',    'M',    'COMM', 'DOT', 'SLSH', 'RSFT',
  'ESC',  'LGUI', 'LALT', MOLYR,  'SPC',  ______, ______, ______, 'LEFT', 'DOWN', 'UP',  'RGHT',
]]
# fmt:on

if __name__ == '__main__':
    Mini48.go()

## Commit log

2024-05-26 ひとまず12x4のキーを配置しました。 基板外形、ネジ穴が未定です。
    [mini48-keyboard.kicad_pcb, mini48-keyboard.kicad_sch, sw_matrix.kicad_sch]
2024-07-08 外形の微調整を行いました。 GNDベタにビアを打ちました。 余分なキーを切り離せるように、基板にスリットをいれました。
    [mini48-keyboard.kicad_pcb, mini48-keyboard.kicad_sch]
2024-07-09 基板のスリットをやめました。 基板外形の微調整を行いました。ネジ穴の位置の微調整を行いました。
    [mini48-keyboard.kicad_pcb]
2024-07-09 JLCPCB DFM Toolのチェック結果を反映しました。
    [mini48-keyboard.kicad_pcb]
2024-08-01 基板の組み立て方法を書いています。
2024-08-14 choc v1ソケットの3Dモデルを追加しました。 3Dモデルは https://github.com/koktoh/keyswitch_model を使用しました。
2024-08-19 FreeCADでケースの設計を始めました。
    [mini48-keyboard.kicad_pcb, mini48-keyboard.step]
2024-08-25 小型の3Dプリンタで印刷できるように、ケースを左右に分割しました。 ケースの接着のため糊代を追加しました。 ケースの深さを変更できるようにパラメタ化しました。
2024-09-26 マウスボタン付きのケースです。 ケースは一体型で設計しました。 3Dプリンタに合わせた分割はスライサーで行います。
2024-10-05 改版にむけたプロジェクトを作り始めました。 マイコン基板をpicoに変更します。 MX用のソケットを追加します。
    [mini48-keyboard_v2_mx_choc.kicad_pcb, mini48-keyboard_v2_mx_choc.kicad_sch, sw_matrix.kicad_sch]
2024-10-11 17mmピッチ版のプロジェクトを作りました。 chocのフットプリントを Keyswitch Kicad Library からコピーしました。
    [mini48-keyboard_v2_p17.kicad_pcb, mini48-keyboard_v2_p17.kicad_sch, sw_matrix_para.kicad_sch]
2024-10-11 ざっくり配線しました。 pico と ae-rp2040 を選択できるようにしました。
    [mini48-keyboard_v2_p17.kicad_pcb, mini48-keyboard_v2_p17.kicad_sch]
2024-10-11 LCDのクロック線周りを微修正。
    [mini48-keyboard_v2_p17.kicad_pcb, mini48-keyboard_v2_p17.kicad_sch]
2024-10-16 マイコンボードを pico のみに変更しました。 スイッチのシートの名前を変えました。
    [mini48-keyboard_v2_p17.kicad_pcb, mini48-keyboard_v2_p17.kicad_sch, sw_matrix.kicad_sch]
2024-10-16 スイッチのシート名を変更しました。
    [mini48-keyboard_v2_mx_choc.kicad_pcb, mini48-keyboard_v2_mx_choc.kicad_sch, sw_matrix_para.kicad_sch]
2024-10-16 MXとchocを並列に接続しました。 基板外形を変更中。
    [mini48-keyboard_v2_mx_choc.kicad_pcb, sw_matrix_para.kicad_sch]
2024-10-16 基板上にUSB type-cのコネクタを実装しました。 picoのTPとジャンパ配線します。
    [mini48-keyboard_v2_mx_choc.kicad_pcb, mini48-keyboard_v2_mx_choc.kicad_sch]
2024-10-19 不足ファイルを追加しました。
    [pimoroni_lcd.kicad_sch]
2024-10-19 OLED / LCD のシンボルとフットプリントを追加しました。 40キーのプロジェクトを追加しました。
    [mini40-keyboard_v2_p17.kicad_pcb, mini40-keyboard_v2_p17.kicad_sch, oled_ssd1132.kicad_sch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]
2024-11-01 kmk を使用したファームウェアです。 また、トラックポイントを接続する改造に対応したqmkのファームウェアです。
2024-11-01 トラックパッドの軸の延長部品を追加しました。
    [tp-stem-test.FCStd]
2024-11-21 マイコンとしてESP32-S3の使用を検討しています。 Rasberry Pi Pico と ESP32-S3 のどちらかを選択して実装する設計です。 主要部品以外は仮の部品・フットプリントです。
    [esp32-s3_mcu.kicad_sch, mini40-keyboard_v2_p17.kicad_pcb, mini40-keyboard_v2_p17.kicad_sch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]
2024-11-27 トラックポイント用の回路を追加しました。
    [mini48-keyboard_v2_mx_choc.kicad_sch, track_point.kicad_sch]
2024-11-28 シンボルパス、フットプリントパスを修正しました。 基板製造に使用したファイルを追加しました。
    [track_point.kicad_sch]
2024-11-28 AE-RP2040 to RPI Pico変換基板のプロジェクトを追加しました。
    [ae-rp2040_to_pico_a.kicad_pcb, ae-rp2040_to_pico_a.kicad_sch]
2024-12-01 やっぱり標準のマイコンはpicoのピン配に合わせる。
    [ae-rp2040_mcu.kicad_sch, mini48-keyboard_v2_mx_choc.kicad_sch, pico_mcu.kicad_sch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]
2024-12-02 ひとまずすべての未配線をなくした版です。 配線は整えていません。 また、GNDプレーンのビアは打っていません。
    [mini48-keyboard_v2_mx_choc.kicad_sch, pico_mcu.kicad_sch, track_point.kicad_sch]
2024-12-24 トラックポイント(2ピースタイプ)の取り付けステーです。 トラックポイントの軸の延長部品です。
    [pico_mcu.kicad_sch, tp-stem.FCStd, tp_stay-Body.stl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]
2024-12-30 2ピースタイプのステーとTP軸の延長を追加しました。
    [tp-stem_t440-Body.stl, tp-stem_t440.FCStd, tp_stay2-Body.stl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]
2025-02-05 pico の GPIO でトラックポイントモジュールにリセットをかけるようにしました。
2025-02-23 picoの位置を左上に変更しました。
    [mini48-keyboard_v2_mx_choc.kicad_sch, pico_mcu.kicad_sch, sw_matrix_para.kicad_sch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]
2025-03-07 KiCad のバージョンを9に上げました。
    [mini48-keyboard_v2_mx_choc.kicad_pcb, mini48-keyboard_v2_mx_choc.kicad_sch, pico_mcu.kicad_sch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]
2025-03-07 トラックポイントの接続部分を別基板にします。 v1基板の改造に使います。
    [trackpoint-unit.kicad_pcb, trackpoint-unit.kicad_sch]
2025-03-08 pico を別基板にするプロジェクトを作りました。
    [pico-unit-top.kicad_pcb, pico-unit-top.kicad_sch, usb-type-c.kicad_sch]
2025-05-08 中止した基板のプロジェクトを削除しました。
    [esp32-s3_mcu.kicad_sch, mini40-keyboard_v2_p17.kicad_pcb, mini40-keyboard_v2_p17.kicad_sch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]
